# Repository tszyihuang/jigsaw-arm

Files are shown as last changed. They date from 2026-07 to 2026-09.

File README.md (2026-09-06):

# JigsawArm — 四轴机械臂视觉拼装系统

基于 **Jetson + YOLOv8 实例分割** 的四轴机械臂视觉拼装系统:摄像头实时识别散落的碎片 → 算法自动拼接并生成爆炸图 → 机械臂按坐标抓取、搬运、旋转放置,完成装配。全程无需人工干预坐标,`read` 一条命令跑完整流程。

<div align="center">

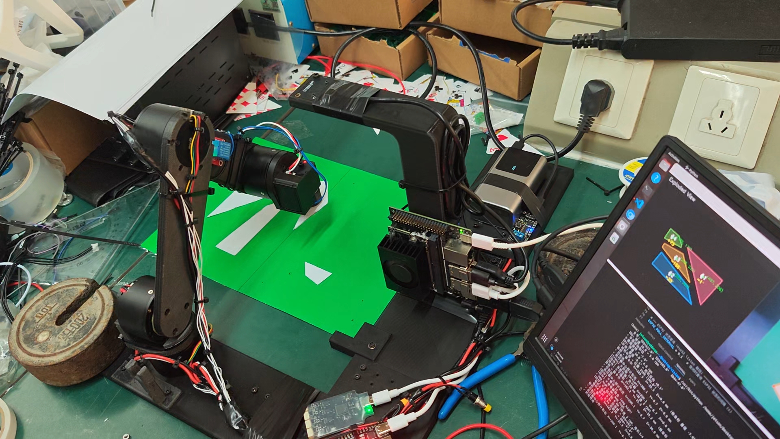
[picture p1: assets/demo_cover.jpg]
点击观看完赛演示视频(Bilibili:《26电赛E题机械臂完赛视频》) (https://www.bilibili.com/video/BV1Ag3Q6mEnW)


**▶ 完赛演示**:点击封面播放《26电赛E题机械臂完赛视频》,96 秒实拍展示机械臂自动拼装的完整流程。

</div>

## 项目简介

本项目是 **2026 年全国大学生电子设计竞赛(26 电赛)E 题** 作品代码库,基于 Jetson 平台实现图像识别、碎片拼接与机械臂自动装配等核心算法:

- **图像识别**:基于 YOLOv8 实例分割,实时识别散落碎片的轮廓与顶点
- **拼接算法**:DFS 回溯匹配边长度、面积比值与四边形角度,自动还原完整拼图并生成爆炸图
- **机械臂装配**:按拼接结果规划抓取、搬运、旋转与放置,自动完成装配

```
摄像头实时 YOLO 分割识别碎片
        │
        ▼
拼接 (DFS 回溯匹配边/面积/角度) + 爆炸图布局
        │
        ▼
输出每个碎片:原始坐标 → (爆炸图坐标, 旋转角)
        │
        ▼
机械臂 抓取 → 搬运 → 舵机旋转 → 放置, 完成装配
```

## 功能特性

- **GPU 实时分割**:YOLOv8 实例分割,GStreamer 硬件加速采集(640×480 @ 60fps),PyTorch CUDA 推理
- **跨帧时域平滑**:碎片顶点按轨迹做 EMA 平滑,抗单帧抖动
- **自动拼接算法**:DFS 回溯 — 边长度匹配 + 面积比值 + 四边形角度三重校验,输出对齐后的完整拼图
- **爆炸图布局**:碎片沿"整体中心→碎片中心"方向推出至外扩包围盒,直观展示每块的放置位置
- **一键装配**:`read` 流程连续采集 10 帧 → 平滑 → 拼接 → 爆炸图 → 独立进程弹窗三合一图,并输出每个碎片的抓取坐标、放置坐标与旋转角
- **绝对坐标控制**:控制台支持毫米级绝对笛卡尔坐标与相机像素坐标(仿射标定,残差 ~0.2mm)双模式
- **基座旋转 → 舵机反向补偿**:基座转动时工具自动反向补偿,保持被抓物体绝对姿态、防止线材缠绕
- **在线调参**:`pid_tune.py` 支持 GIM4310 位置/速度环 PID 在线读取、调整与掉电保存

## 系统架构

```
main_logic.py (业务/控制台) → arm_driver.CartesianArm (笛卡尔级)
    → arm_driver.Arm (电机级) → GIM4310_driver.MotorBus (RS485 总线)
```

- **笛卡尔级** (`CartesianArm`):`move_tool_to` / `move_camera_to`(像素→坐标)/ `go_standby` / `go_home`,分段移动与分关节延时,基座旋转→舵机补偿回调
- **电机级** (`Arm`):关节限位、上电编码器偏置检测、手腕水平参考(ID4 自动维持水平)
- **视觉** (`infer.py` + `reassemble.py`):YOLOv8 分割、顶点平滑、拼接、爆炸图

## 硬件与通信(三路串口 + 摄像头)

| 设备 | 协议/端口 | 说明 |
|---|---|---|
| 4× GIM4310 关节电机 | RS485, 115200, 8N1 | ID1 基座 / ID2 肩 / ID3 肘 / ID4 腕,协议见 `自定义RS485通信协议.md` |
| Feetech STS 工具旋转舵机 | 半双工 TTL, 1Mbps, ID=1 | 正 = 逆时针 |
| ESP32 | 115200, 自动检测端口 | 继电器(电磁铁抓取) + 红绿状态灯 |
| USB 摄像头 | /dev/video0, GStreamer | MJPG 硬件加速, 60fps |

> ⚠ 摄像头**不要两个进程同时打开**(实时窗口与 `read` 流程会互相抢占)。

## 环境依赖

- NVIDIA Jetson(带 CUDA 的 PyTorch)
- Python 3 + PyTorch (GPU) + ultralytics + OpenCV + pyserial + numpy

⚠ 必须使用带 GPU torch 的解释器(如 `/usr/bin/python3`),CPU 版 torch 无法实时推理。

## 快速开始

```bash
# 1. 单图拼接 + 爆炸图测试(无需硬件, 最快的验证方式)
/usr/bin/python3 reassemble.py <image_path>      # 输出 reassembled.jpg / exploded.jpg

# 2. 实时分割窗口
/usr/bin/python3 infer.py                        # q 退出 / s 截图 / r 跑 read 流程 / t 平滑开关

# 3. 主程序(启动流程 + 控制台控制, 需硬件)
/usr/bin/python3 main_logic.py                   # 自动检测 ESP32 串口
/usr/bin/python3 main_logic.py --esp-port /dev/ttyUSB0
/usr/bin/python3 main_logic.py --no              # 调试模式: 跳过视觉
```

### 控制台指令(main_logic.py)

| 指令 | 说明 |
|---|---|
| `<X> <Y> [Z]` | 绝对笛卡尔坐标(mm),Z 缺省保持当前 |
| `n <u> <v> [Z]` | 相机像素坐标 → 执行器坐标后移动 |
| `action` / `put` | 下降到抓取高度 → 继电器吸合/释放 → 回升 |
| `trans <u> <v> [角度]` | 搬运: 抓取点 → 放置点 → [舵机旋转角度] → 放下 |
| `transport <u1> <v1> <u2> <v2> [角度]` | 同 trans,放置点显式指定 |
| `r <角度>` | 舵机相对转动(正 = 逆时针) |
| `read` | 跑完整装配流程(等价于 infer.py 按 R) |
| `t1 ~ t4` | 把 read 输出的第 N 个碎片数据直接传入 transport 执行 |
| `home` / `standby` | 回到待机位置 |
| `ready` | 移动到准备位置 |
| `status` | 显示当前位置 |

`read` 输出格式:`#N(原始坐标)-(爆炸图坐标, 旋转角)`,旋转角约定**顺时针为正**,可直接作为 `trans` 角度使用。

## 项目结构

| 文件 | 作用 |
|---|---|
| `main_logic.py` | 主程序:启动流程 + 控制台指令解析 + 所有动作序列常量 |
| `arm_driver.py` | 机械臂驱动:FK/IK、极坐标换算、工具偏移、相机标定仿射 `CAMERA_A`、`Arm`(电机级)/`CartesianArm`(笛卡尔级) |
| `GIM4310_driver.py` | GIM4310 电机 RS485 驱动(`MotorBus`,地址 1-4) |
| `servo_driver.py` | Feetech STS 串口舵机驱动 |
| `infer.py` | YOLOv8 GPU 实时推理、顶点跨帧 EMA 平滑、`run_read_pipeline`(read 全流程) |
| `reassemble.py` | 碎片拼接(DFS 回溯)、爆炸图、三合一图 |
| `camera_driver.py` | 相机查看工具 |
| `host_test.py` | ESP32 串口通信测试 |
| `pid_tune.py` | GIM4310 PID 在线调参工具 |
| `view_image.py` | 独立进程图片查看器(infer 弹窗调用) |
| `自定义RS485通信协议.md` | GIM4310 RS485 自定义协议文档 |

## 关键约定

- **坐标系**:FK 镜像约定 `x = -r·cos(θ1), y = r·sin(θ1)`;基座角**增大 = 从摄像头视角看顺时针**
- **方向**:舵机**正 = 逆时针**;`read` 输出的旋转角**顺时针为正**(已在 `reassemble.py` 计算源头取反)
- **上电零点**:每次上电以电机当前位置为零点,须保证每次上电姿态一致(失能自由下垂),否则逻辑零点漂移
- **摄像头标定** `CAMERA_A` 为仿射最小二乘拟合(4 组标定点,残差 ~0.6px ≈ 0.2mm),**换机/换相机需重新标定**
- **移动分段**:去程先臂平面后基座,回程先基座后平面,避免工具偏移
- 所有动作参数(待机 Z、下降高度、转速、延时)集中在各文件顶部常量区,直接改常量即可

## 辅助工具

```bash
/usr/bin/python3 camera_driver.py   # 相机画面查看 (GStreamer MJPG 60fps)
/usr/bin/python3 host_test.py       # ESP32 串口测试 (--auto 自动检测)
/usr/bin/python3 pid_tune.py        # 电机 PID 调参
/usr/bin/python3 pid_tune.py --id 2 --pos-kp 60 --pos-ki 1 --save   # 调整 ID2 并保存
```

## 注意事项

- 必须使用带 GPU torch 的解释器,否则推理无法实时
- 摄像头同一时间只允许一个进程打开
- 上电前确保机械臂处于失能自由下垂姿态(零点以此为准)
- 串口路径、模型路径(`infer.py` 的 `MODEL_PATH`)为本地环境配置,换机部署时按需修改

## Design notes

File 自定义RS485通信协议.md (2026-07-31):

# 自定义RS485通信协议_V3.03b3

## 协议版本

*   **Rev.3.01b0 – 2024.01.06**：初始版本；
*   **Rev.3.01b1 – 2024.06.25**：添加更多通信数据帧例子；
*   **Rev.3.02b0 – 2024.11.21**：添加多摩川RS485协议编码器支持；添加抱闸输出控制命令；故障码添加编码器故障；
*   **Rev.3.02b1 – 2025.02.20**：更正文档中0x10命令码表格中命令码字段填写错误；
*   **Rev.3.02b2 – 2025.02.21**：更正0x10、0x11命令关于使能第二编码器的描述；
*   **Rev.3.02b3 – 2025.03.28**：完善通信示例；
*   **Rev.3.02b4 – 2025.04.24**：优化文档内容描述；
*   **Rev.3.03b0 – 2026.03.31**：增加MIT协议内容命令码0x30，0x31，0x32；增加位置速度控制命令码0x25、梯形曲线控制命令码0x26、位置滤波控制模式命令码0x27、位置滤波控制参数设置0x17；增加RS485通信超时配置0x2D；用户参数（命令码0x10、0x11）和电机硬件（命令0x12、0x13）参数的写入和读取内容做了变更；
*   **Rev.3.03b1 – 2026.05.22**：MIT协议内容命令码0x30增加对位置KP，速度KD最大值的设置；
*   **Rev.3.03b2 – 2026.05.27**：更正文档中MIT协议内容的错误描述；
*   **Rev.3.03b3 – 2026.06.09**：更正文档中的数据长度、CRC校验的错误描述；

---

## 协议简介

1.  **波特率与格式**：RS485接口默认通信波特率为**115200**（数据位：8，校验位：0，停止位：1）。可通过上位机的用户参数配置界面配置通信波特率为：921600，460800，115200，57600，38400，19200，9600。所有字节均采用**小端字节顺序**。
2.  **设备地址**：产品出货默认的设备地址为**0x01**。设备地址可通过上位机配置为 1-254；其中，设备地址 0 为广播地址，从机执行命令但不应答主机；设备地址 255 (0xFF) 为公共地址（所有从机均应答该地址命令），主机可单独使用该地址与从机通信获取配置参数。产品当前设备地址可以根据驱动板上绿色LED的闪烁状态获得：
    *   设备地址1：`[ __ -__-__ ]`
    *   设备地址2：`[ __-_-__-_-__ ]`
    *   设备地址3：`[ __-_-_-__-_-_-__ ]` 等。
3.  **总线特性说明**：RS485总线特性决定，总线上只能有一个主机，且从机设备地址不能相同。如果总线有多个设备地址一样的从机，主机通过该地址与从机通信，设备地址相同从机会同时应答主机，从而导致总线短路损坏控制板。因此，**当多个从机挂载在同一总线上时，需提前通过上位机或通信协议配置好从机的设备地址**。

### RS485_V3.x 版本协议通信数据包的命令格式如下：

| 字段名 | 字节数 | 说明 |
| :--- | :--- | :--- |
| **协议头** | 1Byte | 主机发送的协议头为 **0xAE**，从机应答的协议头为 **0xAC**； |
| **包序号** | 1Byte | 从机应答主机的包序号与主机发送给从机的包序号一致； |
| **设备地址** | 1Byte | 地址范围为 0-0xFF；0x00 为广播地址；0xFF 为公共地址；<br>**广播地址**：从机均能收到指令并执行指令，但不应答主机；<br>**公共地址**：从机均能收到指令并执行指令，但应答主机；RS485总线特性决定，当总线连接多个电机时，不能使用公共地址； |
| **命令码** | 1Byte | 不同的命令有不同的命令码； |
| **数据包长度** | 1Byte | 【数据字段】字节数量（可以为0）； |
| **数据字段** | 0-248 (Byte) | 命令码附带的数据； |
| **CRC16校验** | 2Byte | 【协议头】至【数据字段】**CRC16_MODBUS**校验值；校验计算可参考资料包《CRC16_MODBUS校验C语言源码》 |

### 数据类型说明：
*   **1u** – 1个无符号字节
*   **1s** – 1个有符号字节
*   **2u** – 2个无符号字节（小端字节顺序）
*   **2s** – 2个有符号字节（小端字节顺序）
*   **4u** – 4个无符号字节（小端字节顺序）
*   **4s** – 4个有符号字节（小端字节顺序）
*   **4f** – 单精度浮点数（小端字节顺序）
*   **Nb** – 大小为 N 的字节数组

---

## RS485_3.x 版本协议控制命令如下：

| 类别 | 命令码 | 命令功能描述 |
| :---: | :---: | :--- |
| **系统** | **0x00** | 重启从机，主控制器发送该命令包后，从机立即重启不应答主控制器 |
| | **0x0A** | 读取Boot、软件、硬件、RS485协议和CAN协议版本及UID； |
| | **0x0B** | 读单圈绝对值角度、多圈绝对值角度、速度、Q轴电流等实时信息； |
| | **0x0F** | 清除故障； |
| **参数** | **0x10** | 读取用户参数； |
| | **0x11** | 写入并保存用户参数； |
| | **0x12** | 读取电机硬件参数； |
| | **0x13** | 写入并保存电机硬件参数； |
| | **0x14** | 读取运动控制参数； |
| | **0x15** | 写入运动控制参数但不保存； |
| | **0x16** | 写入并保存运动控制参数； |
| | **0x17** | 位置滤波控制参数的读取和配置，断电不保存； |
| | **0x1D** | 设置当前位置为原点； |
| | **0x1E** | 编码器校准；校准过程中电机需空载，且不能干扰电机转动； |
| | **0x1F** | 参数恢复默认值； |
| **控制** | **0x20** | Q轴电流控制；（力矩 = 力矩常数 * Q轴电流） |
| | **0x21** | 速度控制； |
| | **0x22** | 绝对值位置控制； |
| | **0x23** | 相对位置控制； |
| | **0x24** | 电机按照最短的距离回到设定的原点，旋转的角度不大于180度； |
| | **0x25** | 位置速度控制； |
| | **0x26** | 梯形曲线位置控制； |
| | **0x27** | 位置滤波控制； |
| | **0x2D** | RS485通信超时使能、时长、动作类型的读取和配置，断电不保存 |
| | **0x2E** | 抱闸控制开关输出控制； |
| | **0x2F** | 关闭电机输出，电机进入自由态不受控制（电机上电后为该状态）； |
| **运控MIT协议** | **0x30** | 运控模式控制指令中的Pos_Max、Vel_Max、T_Max、Pos_KP_Max、Vel_KD_Max的读取和配置，断电保存； |
| | **0x31** | 读取运控模式下的实时位置、速度、力矩和状态信息； |
| | **0x32** | 运控模式协议控制； |

---

## 协议命令详细说明

### 重启从机；【命令码:0x00】
主控制器发送该命令包后，从机立即重启不应答主控制器。

#### 1. 主控制器(上位机)发送给从机(下位机)
| 序号 | 字段名称 | 类型 | 内容说明(数据) |
| :---: | :--- | :---: | :--- |
| [0] | 协议头 | 1u | 0xAE |
| [1] | 包序号 | 1u | 0x00~0xFF |
| [2] | 设备地址 | 1u | 0x01~0xFE |
| [3] | 命令码 | 1u | **0x00** |
| [4] | 数据包长度 | 1u | 0x00 |
| [5]-[6] | CRC16校验 | 2u | DATA[0]~DATA[4]字节CRC16校验 |

---

### 读取Boot、软件、硬件、RS485协议和CAN协议版本以及唯一序列号；【命令码:0x0A】

#### 1. 主控制器(上位机)发送给从机(下位机)
| 序号 | 字段名称 | 类型 | 内容说明(数据) |
| :---: | :--- | :---: | :--- |
| [0] | 协议头 | 1u | 0xAE |
| [1] | 包序号 | 1u | 0x00~0xFF |
| [2] | 设备地址 | 1u | 0x01~0xFE |
| [3] | 命令码 | 1u | **0x0A** |
| [4] | 数据包长度 | 1u | 0x00 |
| [5]-[6] | CRC16校验 | 2u | DATA[0]~DATA[4]字节CRC16校验 |

#### 2. 从机(下位机)应答主控制器(上位机)
| 序号 | 字段名称 | 类型 | 内容说明(数据) |
| :---: | :--- | :---: | :--- |
| [0] | 协议头 | 1u | 0xAC |
| [1] | 包序号 | 1u | 0x00~0xFF |
| [2] | 设备地址 | 1u | 0x01~0xFE |
| [3] | 命令码 | 1u | **0x0A** |
| [4] | 数据包长度 | 1u | 0x16 |
| [5]-[6] | Boot软件版本 | 2u | |
| [7]-[8] | 应用软件版本 | 2u | |
| [9]-[10] | 硬件型号 | 2u | 驱动板硬件代号； |
| [11] | RS485-自定义 | 1u | RS485-自定义协议版本； |
| [12] | RS485-Modbus | 1u | RS485-Modbus协议版本；（0表示不支持） |
| [13] | CAN-自定义 | 1u | CAN-自定义协议版本； |
| [14] | CAN-CanOpen | 1u | CanOpen协议版本；（0表示不支持） |
| [15]-[26]| UID唯一序列号| 12b | 唯一设备序列号 |
| [27]-[28]| CRC16校验 | 2u | DATA[0]~DATA[26]字节CRC16校验 |

---

### 读取实时数据；单圈分辨率为14位；【命令码:0x0B】
（单圈绝对值角度、多圈绝对值角度、速度、Q轴电流、母线电压、母线电流、工作温度、运行状态、电机状态、故障码）

#### 1. 主控制器(上位机)发送给从机(下位机)
| 序号 | 字段名称 | 类型 | 内容说明(数据) |
| :---: | :--- | :---: | :--- |
| [0] | 协议头 | 1u | 0xAE |
| [1] | 包序号 | 1u | 0x00~0xFF |
| [2] | 设备地址 | 1u | 0x01~0xFE |
| [3] | 命令码 | 1u | **0x0B** |
| [4] | 数据包长度 | 1u | 0x00 |
| [5]-[6] | CRC16校验 | 2u | DATA[0]~DATA[4]字节CRC16校验 |

#### 2. 从机(下位机)应答主控制器(上位机)
| 序号 | 字段名称 | 类型 | 内容说明(数据) |
| :---: | :--- | :---: | :--- |
| [0] | 协议头 | 1u | 0xAC |
| [1] | 包序号 | 1u | 0x00~0xFF |
| [2] | 设备地址 | 1u | 0x01~0xFE |
| [3] | 命令码 | 1u | **0x0B** |
| [4] | 数据包长度 | 1u | 0x16 |
| [5]-[6] | 单圈绝对值角度| 2u | Angle° = value * (360/16384)； |
| [7]-[10]| 多圈绝对值角度| 4s | Total Angle° = value * (360/16384)； |
| [11]-[14]| 机械速度 | 4s | 单位 0.01rpm； |
| [15]-[18]| Q轴电流 | 4s | 单位 0.001A；（力矩 = Q轴电流 * 力矩常数） |
| [19]-[20]| 母线电压 | 2u | 单位 0.01V； |
| [21]-[22]| 母线电流 | 2u | 单位 0.01A；编码器校准过程中该值无效； |
| [23] | 工作温度 | 1u | 单位 ℃； |
| [24] | 运行状态 | 1u | 0:关闭状态 1:电压控制 2:Q轴电流控制 3:速度控制 4:位置控制 |
| [25] | 电机状态 | 1u | 0:失能 其他:使能 |
| [26] | 故障码 | 1u | [Bit0]: 电压故障 [Bit1]: 电流故障 [Bit2]: 温度故障 [Bit3]: 编码器故障 [Bit6]: 硬件故障 [Bit7]: 软件故障 （Bitn表示字节的第n位；Bit0表示第0位） |
| [27]-[28]| CRC16校验 | 2u | DATA[0]~DATA[26]字节CRC16校验 |

---

### 清除故障；【命令码:0x0F】

#### 1. 主控制器(上位机)发送给从机(下位机)
| 序号 | 字段名称 | 类型 | 内容说明(数据) |
| :---: | :--- | :---: | :--- |
| [0] | 协议头 | 1u | 0xAE |
| [1] | 包序号 | 1u | 0x00~0xFF |
| [2] | 设备地址 | 1u | 0x01~0xFE |
| [3] | 命令码 | 1u | **0x0F** |
| [4] | 数据包长度 | 1u | 0x00 |
| [5]-[6] | CRC16校验 | 2u | DATA[0]~DATA[4]字节CRC16校验 |

#### 2. 从机(下位机)应答主控制器(上位机)
| 序号 | 字段名称 | 类型 | 内容说明(数据) |
| :---: | :--- | :---: | :--- |
| [0] | 协议头 | 1u | 0xAC |
| [1] | 包序号 | 1u | 0x00~0xFF |
| [2] | 设备地址 | 1u | 0x01~0xFE |
| [3] | 命令码 | 1u | **0x0F** |
| [4] | 数据包长度 | 1u | 0x01 |
| [5] | 当前故障 | 1u | 位定义同0x0B中的故障码。0x00表示清除成功。 |
| [6]-[7] | CRC16校验 | 2u | DATA[0]~DATA[5]字节CRC16校验 |

---

### 读取用户参数；【命令码:0x10】

#### 1. 主控制器(上位机)发送给从机(下位机)
| 序号 | 字段名称 | 类型 | 内容说明(数据) |
| :---: | :--- | :---: | :--- |
| [0] | 协议头 | 1u | 0xAE |
| [1] | 包序号 | 1u | 0x00~0xFF |
| [2] | 设备地址 | 1u | 0x01~0xFE |
| [3] | 命令码 | 1u | **0x10** |
| [4] | 数据包长度 | 1u | 0x02 |
| [5] | 协议版本 | 1u | V1:0x01；V2:0x02；V3:0x03；不同版本包含内容不同，高版本包含低版本所有内容。 |
| [6] | 保留 | 1u | |
| [7]-[8] | CRC16校验 | 2u | DATA[0]~DATA[6]字节CRC16校验 |

#### 2. 从机(下位机)应答主控制器(上位机)
| 版本区分 | 序号 | 字段名称 | 类型 | 内容说明(数据) |
| :---: | :---: | :--- | :---: | :--- |
| | [0] | 协议头 | 1u | 0xAC |
| | [1] | 包序号 | 1u | 0x00~0xFF |
| | [2] | 设备地址 | 1u | 0x01~0xFE |
| | [3] | 命令码 | 1u | **0x10** |
| | [4] | 数据包长度 | 1u | 0x1C (V1/V2); 0x1E (V3) |
| **V1/V2** | [5]-[6] | 电角度偏移 | 2u | 编码器校准得到的角度偏移； |
| | [7]-[8] | 机械角度偏移| 2u | 零点设置得到的角度偏移； |
| | [9]-[10]| U相电流偏移 | 2u | U相电流校准得到的偏移； |
| | [11]-[12]| V相电流偏移 | 2u | V相电流校准得到的偏移； |
| | [13]-[14]| W相电流偏移 | 2u | W相电流校准得到的偏移； |
| | [15] | 编码器型号 | 1u | 0: AS504x_SPI; 1: Ma7xx_SPI; 2: MT6835_SPI; 3: TLx5012_SSI; 4: AS504x_PWM; 5: Tamagawa |
| | [16] | 改变编码器方向| 1u | 0:不改变方向； 其它:改变方向； |
| | [17] | 使能第二编码器| 1u | 0:不使能； 其它:使能； |
| | [18] | 速度滤波系数 | 1u | 数值1~100表示系数0.01~1； |
| | [19] | 设备地址 | 1u | 地址范围为0x01~0xFE (1~254)； |
| | [20] | RS485波特率 | 1u | 0: 921600; 1: 460800; 2: 115200; 3: 57600; 4: 38400; 5: 19200; 6: 9600 (默认115200) |
| | [21] | CAN波特率 | 1u | 0: 1M; 1: 500K; 2: 250K; 3: 125K; 4: 100K (默认1M) |
| | [22] | 功能拓展 | 1u | [bit0]: CANopen功能； 其它:预留； 置高为开启 |
| | [23]-[24]| 最大母线电压 | 2u | 单位为0.01V |
| | [25] | 报电压故障时长| 1u | 持续过压时长大于该时长，报故障；单位秒； |
| | [26]-[27]| 最大母线电流 | 2u | 单位为0.01A |
| | [28] | 报电流故障时长| 1u | 持续过流时长大于该时长，报故障；单位秒； |
| | [29] | 最大温度 | 1u | 最大温度，单位℃； |
| | [30] | 报温度故障时长| 1u | 持续过温时长大于该时长，报故障；单位秒； |
| **V3** | [31]-[32]| 电流环增益 | 2u | 单位rad/s，为0表示使用电压环 |
| | [33]-[34]| CRC16校验 | 2u | DATA[0]~DATA[32]字节CRC16校验 |

---

### 写入并保存用户参数；【命令码:0x11】

#### 1. 主控制器(上位机)发送给从机(下位机)
主机发送的数据包格式、字段偏移和类型与 **0x10命令的应答格式完全一致**，除了命令码为 **0x11**，数据包长度在V1/V2版本下为0x1A，在V3版本下为0x1C（即不包含前4个协议字段，从第[5]个字节即参数内容开始传输）。

*   **数据包长度 [4]**: V1/V2为 `0x12`，V3为 `0x14`。
*   **具体结构**：同 0x10 从机应答的数据字段 [5] ~ [30](V1/V2) 或 [32](V3)。

#### 2. 从机(下位机)应答主控制器(上位机)
除了应答的命令码不同外，从机应答主机的内容与0x10命令的内容一致。

---

### 读取电机硬件参数；【命令码:0x12】

#### 1. 主控制器(上位机)发送给从机(下位机)
| 序号 | 字段名称 | 类型 | 内容说明(数据) |
| :---: | :--- | :---: | :--- |
| [0] | 协议头 | 1u | 0xAE |
| [1] | 包序号 | 1u | 0x00~0xFF |
| [2] | 设备地址 | 1u | 0x01~0xFE |
| [3] | 命令码 | 1u | **0x12** |
| [4] | 数据包长度 | 1u | 0x00 |
| [5]-[6] | CRC16校验 | 2u | DATA[0]~DATA[4]字节CRC16校验 |

#### 2. 从机(下位机)应答主控制器(上位机)
| 版本区分 | 序号 | 字段名称 | 类型 | 内容说明(数据) |
| :---: | :---: | :--- | :---: | :--- |
| | [0] | 协议头 | 1u | 0xAC |
| | [1] | 包序号 | 1u | 0x00~0xFF |
| | [2] | 设备地址 | 1u | 0x01~0xFE |
| | [3] | 命令码 | 1u | **0x12** |
| | [4] | 数据包长度 | 1u | 0x21 (V3) / 0x1E (V1/V2) |
| **V1/V2** | [5]-[20] | 电机名称 | Nb | 电机名称的ASCII字符 |
| | [21] | 电机极对数 | 1u | |
| | [22]-[25]| 相电阻 | 4f | 两相之间的电阻/2；单位为Ω； |
| | [26]-[29]| 相电感 | 4f | 两相之间的电感/2；单位为mH； |
| | [30]-[33]| 力矩常数 | 4f | 单位为 N·m/A； |
| **V3** | [34] | 减速比 | 1u | 减速比分子低8位 |
| | [35] | 减速比 | 1u | 减速比分子高8位 |
| | [36]-[37]| 减速比 | 2u | 减速比分母 |
| | [38]-[39]| CRC16校验 | 2u | DATA[0]~DATA[37]字节CRC16校验 |

---

### 写入并保存电机硬件参数；【命令码:0x13】

#### 1. 主控制器(上位机)发送给从机(下位机)
*   **命令码 [3]**: **0x13**
*   **数据包长度 [4]**: V1/V2为 `0x1E`，V3为 `0x21`。
*   **字段内容**: 与0x12应答格式相同（去除通信包头）。

#### 2. 从机(下位机)应答主控制器(上位机)
除了应答的命令码不同外，从机应答主机的内容与0x12命令的内容一致。

---

### 读取运动控制参数；【命令码:0x14】

#### 1. 主控制器(上位机)发送给从机(下位机)
| 序号 | 字段名称 | 类型 | 内容说明(数据) |
| :---: | :--- | :---: | :--- |
| [0] | 协议头 | 1u | 0xAE |
| [1] | 包序号 | 1u | 0x00~0xFF |
| [2] | 设备地址 | 1u | 0x01~0xFE |
| [3] | 命令码 | 1u | **0x14** |
| [4] | 数据包长度 | 1u | 0x00 |
| [5]-[6] | CRC16校验 | 2u | DATA[0]~DATA[4]字节CRC16校验 |

#### 2. 从机(下位机)应答主控制器(上位机)
| 序号 | 字段名称 | 类型 | 内容说明(数据) |
| :---: | :--- | :---: | :--- |
| [0] | 协议头 | 1u | 0xAC |
| [1] | 包序号 | 1u | 0x00~0xFF |
| [2] | 设备地址 | 1u | 0x01~0xFE |
| [3] | 命令码 | 1u | **0x14** |
| [4] | 数据包长度 | 1u | 0x18 |
| [5]-[8] | 位置环Kp | 4f | |
| [9]-[12] | 位置环Ki | 4f | |
| [13]-[16]| 位置环输出限制| 4u | 位置模式最大速度，单位为 0.01rpm； |
| [17]-[20]| 速度环Kp | 4f | |
| [21]-[24]| 速度环Ki | 4f | |
| [25]-[28]| 速度环输出限制| 4u | 速度/位置模式最大Q轴电流，单位 0.001A； |
| [29]-[30]| CRC16校验 | 2u | DATA[0]~DATA[28]字节CRC16校验 |

---

### 写入运动控制参数但不保存；【命令码:0x15】

#### 1. 主控制器(上位机)发送给从机(下位机)
| 序号 | 字段名称 | 类型 | 内容说明(数据) |
| :---: | :--- | :---: | :--- |
| [0] | 协议头 | 1u | 0xAE |
| [1] | 包序号 | 1u | 0x00~0xFF |
| [2] | 设备地址 | 1u | 0x01~0xFE |
| [3] | 命令码 | 1u | **0x15** |
| [4] | 数据包长度 | 1u | 0x18 |
| [5]-[8] | 位置环Kp | 4f | |
| [9]-[12] | 位置环Ki | 4f | |
| [13]-[16]| 位置环输出限制| 4u | 位置模式最大速度，单位为 0.01rpm； |
| [17]-[20]| 速度环Kp | 4f | |
| [21]-[24]| 速度环Ki | 4f | |
| [25]-[28]| 速度环输出限制| 4u | 速度/位置模式最大Q轴电流，单位 0.001A； |
| [29]-[30]| CRC16校验 | 2u | DATA[0]~DATA[28]字节CRC16校验 |

#### 2. 从机(下位机)应答主控制器(上位机)
除了应答的命令码不同外，从机应答主机的内容与0x14命令的内容一致。

---

### 写入并保存运动控制参数；【命令码:0x16】

#### 1. 主控制器(上位机)发送给从机(下位机)
除了发送的命令码（**0x16**）不同外，主机发送给从机的内容与0x15命令的内容一致；

#### 2. 从机(下位机)应答主控制器(上位机)
除了应答的命令码不同外，从机应答主机的内容与0x14命令的内容一致；

---

### 位置滤波控制参数的读取和配置，断电不保存；【命令码:0x17】

#### 1. 主控制器(上位机)发送给从机(下位机)
| 序号 | 字段名称 | 类型 | 内容说明(数据) |
| :---: | :--- | :---: | :--- |
| [0] | 协议头 | 1u | 0xAE |
| [1] | 包序号 | 1u | 0x00~0xFF |
| [2] | 设备地址 | 1u | 0x01~0xFE |
| [3] | 命令码 | 1u | **0x17** |
| [4] | 数据包长度 | 1u | **[0x00，读取参数]**、**[0x0A，配置参数]** |
| [5]-[6] | 位置滤波带宽 | 2u | 位置滤波带宽，单位为Hz；默认50Hz； |
| [7]-[10]| 位置滤波转动惯量| 4f | 转动惯量，单位为 N·m/(turn/s²)，0表示禁用电流前馈；默认0.001N·m/(turn/s²)； |
| [11]-[14]| 位置滤波控制电流前馈限制 | 4u | 位置滤波模式最大前馈电流，单位0.001A；默认1A； |
| [15]-[16]| CRC16校验 | 2u | DATA[0]~DATA[14]字节CRC16校验 |

#### 2. 从机(下位机)应答主控制器(上位机)
| 序号 | 字段名称 | 类型 | 内容说明(数据) |
| :---: | :--- | :---: | :--- |
| [0] | 协议头 | 1u | 0xAC |
| [1] | 包序号 | 1u | 0x00~0xFF |
| [2] | 设备地址 | 1u | 0x01~0xFE |
| [3] | 命令码 | 1u | **0x17** |
| [4] | 数据包长度 | 1u | 0x0A |
| [5]-[6] | 位置滤波带宽 | 2u | 位置滤波带宽，单位为Hz |
| [7]-[10]| 位置滤波转动惯量| 4f | 转动惯量，单位为 N·m/(turn/s²)，0表示禁用电流前馈 |
| [11]-[14]| 位置滤波控制电流前馈限制 | 4u | 位置滤波模式最大前馈电流，单位0.001A； |
| [15]-[16]| CRC16校验 | 2u | DATA[0]~DATA[14]字节CRC16校验 |

---

### 设置当前位置为原点；【命令码:0x1D】

#### 1. 主控制器(上位机)发送给从机(下位机)
| 序号 | 字段名称 | 类型 | 内容说明(数据) |
| :---: | :--- | :---: | :--- |
| [0] | 协议头 | 1u | 0xAE |
| [1] | 包序号 | 1u | 0x00~0xFF |
| [2] | 设备地址 | 1u | 0x01~0xFE |
| [3] | 命令码 | 1u | **0x1D** |
| [4] | 数据包长度 | 1u | 0x00 |
| [5]-[6] | CRC16校验 | 2u | DATA[0]~DATA[4]字节CRC16校验 |

#### 2. 从机(下位机)应答主控制器(上位机)
| 序号 | 字段名称 | 类型 | 内容说明(数据) |
| :---: | :--- | :---: | :--- |
| [0] | 协议头 | 1u | 0xAC |
| [1] | 包序号 | 1u | 0x00~0xFF |
| [2] | 设备地址 | 1u | 0x01~0xFE |
| [3] | 命令码 | 1u | **0x1D** |
| [4] | 数据包长度 | 1u | 0x02 |
| [5]-[6] | 机械角度偏移 | 2u | 设定原点后当前电机的电偏移量/偏移角 |
| [7]-[8] | CRC16校验 | 2u | DATA[0]~DATA[6]字节CRC16校验 |

---

### 编码器校准；【命令码:0x1E】
考虑到校准结果的准确性，编码器校准过程中电机需空载，且不能干扰电机转动；如需停止当前编码器校准，可发送0x2F命令停止操作。

#### 1. 主控制器(上位机)发送给从机(下位机)
| 序号 | 字段名称 | 类型 | 内容说明(数据) |
| :---: | :--- | :---: | :--- |
| [0] | 协议头 | 1u | 0xAE |
| [1] | 包序号 | 1u | 0x00~0xFF |
| [2] | 设备地址 | 1u | 0x01~0xFE |
| [3] | 命令码 | 1u | **0x1E** |
| [4] | 数据包长度 | 1u | 0x00 |
| [5]-[6] | CRC16校验 | 2u | DATA[0]~DATA[4]字节CRC16校验 |

#### 2. 从机(下位机)应答主控制器(上位机)
除了应答的命令码不同外，从机应答主机的内容与0x0B命令的内容一致；

---

### 参数恢复默认值；【命令码:0x1F】
（设备地址、编码器校准参数、电机硬件参数不变）

#### 1. 主控制器(上位机)发送给从机(下位机)
| 序号 | 字段名称 | 类型 | 内容说明(数据) |
| :---: | :--- | :---: | :--- |
| [0] | 协议头 | 1u | 0xAE |
| [1] | 包序号 | 1u | 0x00~0xFF |
| [2] | 设备地址 | 1u | 0x01~0xFE |
| [3] | 命令码 | 1u | **0x1F** |
| [4] | 数据包长度 | 1u | 0x00 |
| [5]-[6] | CRC16校验 | 2u | DATA[0]~DATA[4]字节CRC16校验 |

#### 2. 从机(下位机)应答主控制器(上位机)
| 序号 | 字段名称 | 类型 | 内容说明(数据) |
| :---: | :--- | :---: | :--- |
| [0] | 协议头 | 1u | 0xAC |
| [1] | 包序号 | 1u | 0x00~0xFF |
| [2] | 设备地址 | 1u | 0x01~0xFE |
| [3] | 命令码 | 1u | **0x1F** |
| [4] | 数据包长度 | 1u | 0x00 |
| [5]-[6] | CRC16校验 | 2u | DATA[0]~DATA[4]字节CRC16校验 |

---

### Q轴电流控制；【命令码:0x20】

#### 1. 主控制器(上位机)发送给从机(下位机)
| 序号 | 字段名称 | 类型 | 内容说明(数据) |
| :---: | :--- | :---: | :--- |
| [0] | 协议头 | 1u | 0xAE |
| [1] | 包序号 | 1u | 0x00~0xFF |
| [2] | 设备地址 | 1u | 0x01~0xFE |
| [3] | 命令码 | 1u | **0x20** |
| [4] | 数据包长度 | 1u | 0x08 |
| [5]-[8] | 目标Q轴电流 | 4s | 单位0.001A；力矩 = 目标电流 * 力矩常数； |
| [9]-[12] | Q轴电流斜率 | 4u | 单位0.001A/S；值为0时为最大斜率； |
| [13]-[14]| CRC16校验 | 2u | DATA[0]~DATA[12]字节CRC16校验 |

#### 2. 从机(下位机)应答主控制器(上位机)
除了应答的命令码不同外，从机应答主机的内容与0x0B命令的内容一致；

---

### 速度控制；【命令码:0x21】

#### 1. 主控制器(上位机)发送给从机(下位机)
| 序号 | 字段名称 | 类型 | 内容说明(数据) |
| :---: | :--- | :---: | :--- |
| [0] | 协议头 | 1u | 0xAE |
| [1] | 包序号 | 1u | 0x00~0xFF |
| [2] | 设备地址 | 1u | 0x01~0xFE |
| [3] | 命令码 | 1u | **0x21** |
| [4] | 数据包长度 | 1u | 0x08 |
| [5]-[8] | 目标速度 | 4s | 单位为0.01rpm； |
| [9]-[12] | 加速度 | 4u | 单位为0.01rpm/s；值为0为最大加速度； |
| [13]-[14]| CRC16校验 | 2u | DATA[0]~DATA[12]字节CRC16校验 |

#### 2. 从机(下位机)应答主控制器(上位机)
除了应答的命令码不同外，从机应答主机的内容与0x0B命令的内容一致；

---

### 绝对值位置控制；【命令码:0x22】

#### 1. 主控制器(上位机)发送给从机(下位机)
| 序号 | 字段名称 | 类型 | 内容说明(数据) |
| :---: | :--- | :---: | :--- |
| [0] | 协议头 | 1u | 0xAE |
| [1] | 包序号 | 1u | 0x00~0xFF |
| [2] | 设备地址 | 1u | 0x01~0xFE |
| [3] | 命令码 | 1u | **0x22** |
| [4] | 数据包长度 | 1u | 0x04 |
| [5]-[8] | 绝对值位置 | 4s | 单位为Count；旋转一圈为16384Count； |
| [9]-[10] | CRC16校验 | 2u | DATA[0]~DATA[8]字节CRC16校验 |

#### 2. 从机(下位机)应答主控制器(上位机)
除了应答的命令码不同外，从机应答主机的内容与0x0B命令的内容一致；

---

### 相对位置控制；【命令码:0x23】

#### 1. 主控制器(上位机)发送给从机(下位机)
| 序号 | 字段名称 | 类型 | 内容说明(数据) |
| :---: | :--- | :---: | :--- |
| [0] | 协议头 | 1u | 0xAE |
| [1] | 包序号 | 1u | 0x00~0xFF |
| [2] | 设备地址 | 1u | 0x01~0xFE |
| [3] | 命令码 | 1u | **0x23** |
| [4] | 数据包长度 | 1u | 0x04 |
| [5]-[8] | 相对位置 | 4s | 单位为Count；旋转一圈为16384Count； |
| [9]-[10] | CRC16校验 | 2u | DATA[0]~DATA[8]字节CRC16校验 |

#### 2. 从机(下位机)应答主控制器(上位机)
除了应答的命令码不同外，从机应答主机的内容与0x0B命令的内容一致；

---

### 最短距离回原点；【命令码:0x24】

#### 1. 主控制器(上位机)发送给从机(下位机)
| 序号 | 字段名称 | 类型 | 内容说明(数据) |
| :---: | :--- | :---: | :--- |
| [0] | 协议头 | 1u | 0xAE |
| [1] | 包序号 | 1u | 0x00~0xFF |
| [2] | 设备地址 | 1u | 0x01~0xFE |
| [3] | 命令码 | 1u | **0x24** |
| [4] | 数据包长度 | 1u | 0x00 |
| [5]-[6] | CRC16校验 | 2u | DATA[0]~DATA[4]字节CRC16校验 |

#### 2. 从机(下位机)应答主控制器(上位机)
除了应答的命令码不同外，从机应答主机的内容与0x0B命令的内容一致；

---

### 位置速度控制；【命令码:0x25】

#### 1. 主控制器(上位机)发送给从机(下位机)
| 序号 | 字段名称 | 类型 | 内容说明(数据) |
| :---: | :--- | :---: | :--- |
| [0] | 协议头 | 1u | 0xAE |
| [1] | 包序号 | 1u | 0x00~0xFF |
| [2] | 设备地址 | 1u | 0x01~0xFE |
| [3] | 命令码 | 1u | **0x25** |
| [4] | 数据包长度 | 1u | 0x09 |
| [5] | 位置类型 | 1u | [00 : 绝对值位置] [01 : 相对值位置] |
| [6]-[9] | 目标位置 | 4s | 单位为Count；旋转一圈为16384Count； |
| [10]-[13]| 目标速度 | 4u | 单位为0.01rpm |
| [14]-[15]| CRC16校验 | 2u | DATA[0]~DATA[13]字节CRC16校验 |

#### 2. 从机(下位机)应答主控制器(上位机)
除了应答的命令码不同外，从机应答主机的内容与0x0B命令的内容一致；

---

### 梯形曲线位置控制；【命令码:0x26】

#### 1. 主控制器(上位机)发送给从机(下位机)
| 序号 | 字段名称 | 类型 | 内容说明(数据) |
| :---: | :--- | :---: | :--- |
| [0] | 协议头 | 1u | 0xAE |
| [1] | 包序号 | 1u | 0x00~0xFF |
| [2] | 设备地址 | 1u | 0x01~0xFE |
| [3] | 命令码 | 1u | **0x26** |
| [4] | 数据包长度 | 1u | 0x11 |
| [5] | 位置类型 | 1u | [00 : 绝对值位置] [01 : 相对值位置] |
| [6]-[9] | 目标位置 | 4s | 单位为Count；旋转一圈为16384Count； |
| [10]-[13]| 最大速度 | 4u | 单位为0.01rpm |
| [14]-[17]| 最大加速度 | 4u | 单位为0.01rpm/s |
| [18]-[21]| 最大减速度 | 4u | 单位为0.01rpm/s |
| [22]-[23]| CRC16校验 | 2u | DATA[0]~DATA[21]字节CRC16校验 |

#### 2. 从机(下位机)应答主控制器(上位机)
除了应答的命令码不同外，从机应答主机的内容与0x0B命令的内容一致；

---

### 位置滤波控制；【命令码:0x27】

#### 1. 主控制器(上位机)发送给从机(下位机)
| 序号 | 字段名称 | 类型 | 内容说明(数据) |
| :---: | :--- | :---: | :--- |
| [0] | 协议头 | 1u | 0xAE |
| [1] | 包序号 | 1u | 0x00~0xFF |
| [2] | 设备地址 | 1u | 0x01~0xFE |
| [3] | 命令码 | 1u | **0x27** |
| [4] | 数据包长度 | 1u | 0x09 |
| [5] | 位置类型 | 1u | [00 : 绝对值位置] [01 : 相对值位置] |
| [6]-[9] | 目标位置 | 4s | 单位为Count；旋转一圈为16384Count； |
| [10]-[13]| 最大速度 | 4u | 单位为0.01rpm； |
| [14]-[15]| CRC16校验 | 2u | DATA[0]~DATA[13]字节CRC16校验 |

#### 2. 从机(下位机)应答主控制器(上位机)
除了应答的命令码不同外，从机应答主机的内容与0x0B命令的内容一致；

---

### RS485通信超时使能、时长、动作类型的读取和配置，断电不保存；【命令码:0x2D】

#### 1. 主控制器(上位机)发送给从机(下位机)
| 序号 | 字段名称 | 类型 | 内容说明(数据) |
| :---: | :--- | :---: | :--- |
| [0] | 协议头 | 1u | 0xAE |
| [1] | 包序号 | 1u | 0x00~0xFF |
| [2] | 设备地址 | 1u | 0x01~0xFE |
| [3] | 命令码 | 1u | **0x2D** |
| [4] | 数据包长度 | 1u | **[0x00, 读取参数]**、**[0x04, 配置参数]** |
| [5] | 通信超时使能 | 1u | 0x00: 失能 0x01: 使能；默认为失能 |
| [6]-[7] | 时长 | 2u | 单位ms；默认为5000ms |
| [8] | 动作类型 | 1u | 超时使能且时长大于设定值，报通信故障并失能电机；<br>可配置附加动作：<br>[Bit0]：通信故障码不允许软件清除；<br>[Bit1]：抱闸开关断开；<br>默认为0x00，没有任何额外动作； |
| [9]-[10] | CRC16校验 | 2u | DATA[0]~DATA[8]字节CRC16校验 |

#### 2. 从机(下位机)应答主控制器(上位机)
| 序号 | 字段名称 | 类型 | 内容说明(数据) |
| :---: | :--- | :---: | :--- |
| [0] | 协议头 | 1u | 0xAC |
| [1] | 包序号 | 1u | 0x00~0xFF |
| [2] | 设备地址 | 1u | 0x01~0xFE |
| [3] | 命令码 | 1u | **0x2D** |
| [4] | 数据包长度 | 1u | 0x04 |
| [5] | 通信超时使能 | 1u | 0x00: 失能 0x01: 使能 |
| [6]-[7] | 时长 | 2u | 单位ms； |
| [8] | 动作类型 | 1u | [Bit0]：通信故障码不允许软件清除； [Bit1]：抱闸开关断开； |
| [9]-[10] | CRC16校验 | 2u | DATA[0]~DATA[8]字节CRC16校验 |

---

### 抱闸控制开关输出控制；【命令码:0x2E】

#### 1. 主控制器(上位机)发送给从机(下位机)
| 序号 | 字段名称 | 类型 | 内容说明(数据) |
| :---: | :--- | :---: | :--- |
| [0] | 协议头 | 1u | 0xAE |
| [1] | 包序号 | 1u | 0x00~0xFF |
| [2] | 设备地址 | 1u | 0x01~0xFE |
| [3] | 命令码 | 1u | **0x2E** |
| [4] | 数据包长度 | 1u | 0x01 |
| [5] | 操作类型 | 1u | 0x00: 开关断开 0x01: 开关闭合 0xFF: 读取状态 |
| [6]-[7] | CRC16校验 | 2u | DATA[0]~DATA[5]字节CRC16校验 |

#### 2. 从机(下位机)应答主控制器(上位机)
| 序号 | 字段名称 | 类型 | 内容说明(数据) |
| :---: | :--- | :---: | :--- |
| [0] | 协议头 | 1u | 0xAC |
| [1] | 包序号 | 1u | 0x00~0xFF |
| [2] | 设备地址 | 1u | 0x01~0xFE |
| [3] | 命令码 | 1u | **0x2E** |
| [4] | 数据包长度 | 1u | 0x01 |
| [5] | 操作类型 | 1u | 0x00: 开关断开 0x01: 开关闭合 |
| [6]-[7] | CRC16校验 | 2u | DATA[0]~DATA[5]字节CRC16校验 |

---

### 电机失能 OFF；【命令码:0x2F】

#### 1. 主控制器(上位机)发送给从机(下位机)
| 序号 | 字段名称 | 类型 | 内容说明(数据) |
| :---: | :--- | :---: | :--- |
| [0] | 协议头 | 1u | 0xAE |
| [1] | 包序号 | 1u | 0x00~0xFF |
| [2] | 设备地址 | 1u | 0x01~0xFE |
| [3] | 命令码 | 1u | **0x2F** |
| [4] | 数据包长度 | 1u | 0x00 |
| [5]-[6] | CRC16校验 | 2u | DATA[0]~DATA[4]字节CRC16校验 |

#### 2. 从机(下位机)应答主控制器(上位机)
除了应答的命令码不同外，从机应答主机的内容与0x0B命令的内容一致；

---

## 运控模式：MIT 类型协议控制方式

为兼容不同规格的电机，协议内容支持根据当前电机的实际参数或使用需求，配置位置、速度和力矩的最大值。
需要注意的是，当前运控模式协议中，位置、速度和力矩的单位与前文有所不同：
1.  **位置单位**：弧度 (rad)，其中 2π rad 对应 360°；
2.  **速度单位**：弧度每秒 (rad/s)，其中 2π rad/s 对应 60 转/分 (rpm)；
3.  **力矩单位**：牛顿·米 (N·m)，需通过上位机正确配置电机力矩常数；

---

### 读取和配置 MIT 运动控制参数，断电保存；【命令码:0x30】

#### 1. 主控制器(上位机)发送给从机(下位机)
| 序号 | 字段名称 | 类型 | 内容说明(数据) |
| :---: | :--- | :---: | :--- |
| [0] | 协议头 | 1u | 0xAE |
| [1] | 包序号 | 1u | 0x00~0xFF |
| [2] | 设备地址 | 1u | 0x01~0xFE |
| [3] | 命令码 | 1u | **0x30** |
| [4] | 数据包长度 | 1u | **[0x00，读取参数]**、**[0x0A，配置参数]** |
| [5]-[6] | Pos_Max | 2u | 配置运控模式位置最大值，单位0.1rad；默认为95.5rad |
| [7]-[8] | Vel_Max | 2u | 配置运控模式速度最大值，单位0.01rad/s；默认为45rad/s |
| [9]-[10] | T_Max | 2u | 配置运控模式力矩最大值，单位0.01N·m；默认为18N·m； |
| [11]-[12]| Pos_KP_Max | 2u | 配置运控模式位置KP最大值，默认值为500，最大可配置到1000； |
| [13]-[14]| Vel_KD_Max | 2u | 配置运控模式速度KD最大值，默认值为5，最大可配置到100； |
| [15]-[16]| CRC16校验 | 2u | DATA[0]~DATA[14]字节CRC16校验 |

#### 2. 从机(下位机)应答主控制器(上位机)
| 序号 | 字段名称 | 类型 | 内容说明(数据) |
| :---: | :--- | :---: | :--- |
| [0] | 协议头 | 1u | 0xAC |
| [1] | 包序号 | 1u | 0x00~0xFF |
| [2] | 设备地址 | 1u | 0x01~0xFE |
| [3] | 命令码 | 1u | **0x30** |
| [4] | 数据包长度 | 1u | 0x0A |
| [5]-[6] | Pos_Max | 2u | 配置运控模式位置最大值，单位0.1rad； |
| [7]-[8] | Vel_Max | 2u | 配置运控模式速度最大值，单位0.01rad/s； |
| [9]-[10] | T_Max | 2u | 配置运控模式力矩最大值，单位0.01N·m； |
| [11]-[12]| Pos_KP_Max | 2u | 配置运控模式位置KP最大值，默认值为500，最大可配置到1000； |
| [13]-[14]| Vel_KD_Max | 2u | 配置运控模式速度KD最大值，默认值为5，最大可配置到100； |
| [15]-[16]| CRC16校验 | 2u | DATA[0]~DATA[14]字节CRC16校验 |

---

### 读取运控模式下的实时位置、速度、力矩和状态信息；【命令码:0x31】

#### 1. 主控制器(上位机)发送给从机(下位机)
| 序号 | 字段名称 | 类型 | 内容说明(数据) |
| :---: | :--- | :---: | :--- |
| [0] | 协议头 | 1u | 0xAE |
| [1] | 包序号 | 1u | 0x00~0xFF |
| [2] | 设备地址 | 1u | 0x01~0xFE |
| [3] | 命令码 | 1u | **0x31** |
| [4] | 数据包长度 | 1u | 0x00 |
| [5]-[6] | CRC16校验 | 2u | DATA[0]~DATA[4]字节CRC16校验 |

#### 2. 从机(下位机)应答主控制器(上位机)
| 序号 | 字段名称 | 类型 | 内容说明(数据) |
| :---: | :--- | :---: | :--- |
| [0] | 协议头 | 1u | 0xAC |
| [1] | 包序号 | 1u | 0x00~0xFF |
| [2] | 设备地址 | 1u | 0x01~0xFE |
| [3] | 命令码 | 1u | **0x31** |
| [4] | 数据包长度 | 1u | 0x09 |
| [5]-[6] | 机械位置 | 16bit | [5]为高8位，[6]为低8位；[0~65535]对应 (-Pos_Max ~ Pos_Max)； |
| [7]-[8] | 机械速度 | 12bit | [7]为高8位，[8]-Bit[7:4]为低4位；[0~4095]对应 (-Vel_Max ~ Vel_Max)； |
| [8]-[9] | 力矩 | 12bit | [8]-Bit[3:0]为高4位，[9]为低8位；[0~4095]对应 (-T_Max ~ T_Max)； |
| [10] | 状态信息 | 1u | [Bit0]: 为1表示处于运控模式；<br>[Bit1]: 为1表示系统有故障；<br>[Bit2~7]: 预留 |
| [11] | 工作温度 | 1u | 单位 ℃； |
| [12]-[13]| 预留 | 2u | 预留区域，默认0； |
| [14]-[15]| CRC16校验 | 2u | DATA[0]~DATA[13]字节CRC16校验 |

---

### 运控模式控制命令；【命令码:0x32】

#### 1. 主控制器(上位机)发送给从机(下位机)
| 序号 | 字段名称 | 类型 | 内容说明(数据) |
| :---: | :--- | :---: | :--- |
| [0] | 协议头 | 1u | 0xAE |
| [1] | 包序号 | 1u | 0x00~0xFF |
| [2] | 设备地址 | 1u | 0x01~0xFE |
| [3] | 命令码 | 1u | **0x32** |
| [4] | 数据包长度 | 1u | 0x08 |
| [5]-[6] | 目标位置 | 16bit | [5]为高8位，[6]为低8位；[0~65535]对应 (-Pos_Max ~ Pos_Max)； |
| [7]-[8] | 目标速度 | 12bit | [7]为高8位，[8]-Bit[7:4]为低4位；[0~4095]对应 (-Vel_Max ~ Vel_Max)； |
| [8]-[9] | 位置增益Kp值| 12bit | [8]-Bit[3:0]为高4位，[9]为低8位；[0~4095]对应 [0~Pos_KP_Max]； |
| [10]-[11]| 速度增益Kd值| 12bit | [10]为高8位，[11]-Bit[7:4]为低4位；[0~4095]对应 [0~Vel_KD_Max]； |
| [11]-[12]| 目标力矩 | 12bit | [11]-Bit[3:0]为高4位，[12]为低8位；[0~4095]对应 (-T_Max ~ T_Max)； |
| [13]-[14]| CRC16校验 | 2u | DATA[0]~DATA[12]字节CRC16校验 |

#### 2. 从机（下位机）应答主控制器（上位机）
除了应答的命令码不同外，从机应答主机的内容与0x31命令的内容一致；

---

## 自定义通信协议通信示例

### [0x0B 命令] - 读取单圈绝对值角度、多圈绝对值角度、速度、Q轴电流等实时信息；
假设从机设备地址为 1，通信数据帧如下：

**主控制器发送数据帧 (Hex):** （数据包长度为0，数据字段为空）
```
AE 00 01 0B 00 9B 28
```

**从机应答数据帧 (Hex):**
```
AC 00 01 0B 16 27 39 27 39 19 00 1E C8 00 00 19 00 00 00 94 0C 04 00 24 03 01 00 3B DD
```
*(标注：①: `27 39`，②: `27 39 19 00`，③: `1E C8 00 00`，④: `19 00 00 00`，⑤: `94 0C`，⑥: `04 00`，⑦: `24`，⑧: `03`，⑨: `01`，⑩: `00`)*

**根据 0x0B 协议内容解析从机应答数据字段：**
| 序号 | 字段名称 | 16进制(Hex) | 10进制(Dec) | 对应参数值/含义 |
| :---: | :--- | :--- | :--- | :--- |
| ① | 单圈绝对值角度 | `0x3927` | 14631 | 14631 * (360/16384) = 321.48° |
| ② | 多圈绝对值角度 | `0x00193927` | 1653031 | 1653031 * (360/16384) = 36321.48° |
| ③ | 机械速度 | `0x0000C81E` | 51230 | 51230 * 0.01 = 512.3rpm |
| ④ | Q轴电流 | `0x00000019` | 25 | 25 * 0.001 = 0.025A |
| ⑤ | 母线电压 | `0x0C94` | 3220 | 3220 * 0.01 = 32.2V |
| ⑥ | 母线电流 | `0x0004` | 4 | 4 * 0.01 = 0.04A |
| ⑦ | 工作温度 | `0x24` | 36 | 36℃ |
| ⑧ | 运行状态 | `0x03` | 3 | 速度控制模式 |
| ⑨ | 电机状态 | `0x01` | 1 | 使能 |
| ⑩ | 故障码 | `0x00` | 0 | 无故障 |

---

### [0x0F 命令] - 清除故障；
假设从机地址为 1，通信数据帧如下：

**主控制器发送数据帧 (Hex):** （数据包长度为0，数据字段为空）
```
AE 00 01 0F 00 99 E8
```

**从机应答数据帧 (Hex):**
```
AC 00 01 0F 01 00 28 18
```
*(标注 ①: `00`)*

**根据 0x0F 协议内容解析主控制器接收数据字段：**
*   **① 故障码**: `0x00`。表示没有故障。

---

### [0x20 命令] - Q轴电流控制；
目标Q轴电流 1A；假设从机地址为 1，通信数据帧如下：

**主控制器发送数据帧 (Hex):** （数据包长度为0x08）
```
AE 00 01 20 08 E8 03 00 00 00 00 00 00 CB 7C
```
*(标注 ①: `E8 03 00 00`，②: `00 00 00 00`)*

**从机应答数据帧 (Hex):** （应答内容格式与 0x0B 命令一致）
```
AC 00 01 20 16 27 39 27 39 19 00 1E C8 00 00 19 00 00 00 94 0C 04 00 24 03 10 00 AD F3
```

**根据 0x20 协议内容解析主控制器发送数据字段：**
*   **① Q轴电流**: `0x000003E8` (10进制: 1000) -> Q轴电流 = 1000 * 0.001 = 1A
*   **② 电流斜率**: `0x00000000` (10进制: 0) -> Q轴电流斜率 0，最大斜率

---

### [0x21 命令] - 速度控制；
目标速度 100rpm，假设从机设备地址为 1，通信数据帧如下：

**主控制器发送数据帧 (Hex):** （数据包长度为0x08）
```
AE 00 01 21 08 10 27 00 00 00 00 00 00 F0 59
```
*(标注 ①: `10 27 00 00`，②: `00 00 00 00`)*

**从机应答数据帧 (Hex):** （应答内容格式与 0x0B 命令一致）
```
AC 00 01 21 16 27 39 27 39 19 00 1E C8 00 00 19 00 00 00 94 0C 04 00 24 03 10 00 F0 66
```

**根据 0x21 协议内容解析主控制器发送数据字段：**
*   **① 速度**: `0x00002710` (10进制: 10000) -> 速度 = 10000 * 0.01 = 100rpm
*   **② 加速度**: `0x00000000` (10进制: 0) -> 加速度 0，最大加速度

---

### [0x22 命令] - 绝对值位置控制；
目标位置 16384count；假设从机设备地址为 1，通信数据帧如下：

**主控制器发送数据帧 (Hex):** （数据包长度为0x04）
```
AE 00 01 22 04 00 40 00 00 58 C1
```
*(标注 ①: `00 40 00 00`)*

**从机应答数据帧 (Hex):** （应答内容格式与 0x0B 命令一致）
```
AC 00 01 22 16 27 39 27 39 19 00 1E C8 00 00 19 00 00 00 94 0C 04 00 24 03 10 00 14 99
```

**根据 0x22 协议内容解析主控制器发送数据字段：**
*   **① 绝对值位置**: `0x00004000` (10进制: 16384) -> 16384 * (360/16384) = 360°，电机旋转到多圈绝对值位置 16384count 位置；

---

### [0x23 命令] - 相对位置控制；
转动角度 90°；假设从机设备地址为 1，通信数据帧如下：

**主控制器发送数据帧 (Hex):** （数据包长度为0x04）
```
AE 00 01 23 04 00 10 00 00 59 01
```
*(标注 ①: `00 10 00 00`)*

**从机应答数据帧 (Hex):** （应答内容格式与 0x0B 命令一致）
```
AC 00 01 23 16 27 39 27 39 19 00 1E C8 00 00 19 00 00 00 94 0C 04 00 24 03 10 00 49 0C
```

**根据 0x23 协议内容解析主控制器发送数据字段：**
*   **① 相对位置**: `0x00001000` (10进制: 4096) -> 4096 * (360/16384) = 90°，电机基于当前位置正方向旋转 90 度；

---

### [0x26 命令] - 梯形曲线绝对位置控制；
转动角度 90°；假设从机设备地址为 1，通信数据帧如下：

**主控制器发送数据帧 (Hex):** （数据包长度为0x11）
```
AE 00 01 26 11 00 00 10 00 00 E8 03 00 00 E8 03 00 00 E8 03 00 00 70 75
```
*(标注 ①: `00`，②: `00 10 00 00`，③: `E8 03 00 00`，④: `E8 03 00 00`，⑤: `E8 03 00 00`)*

**从机应答数据帧 (Hex):** （应答内容格式与 0x0B 命令一致）
```
AC 00 01 26 16 27 39 27 39 19 00 1E C8 00 00 19 00 00 00 94 0C 04 00 24 03 10 00 66 4C
```

**根据 0x26 协议内容解析主控制器发送数据字段：**
*   **① 控制模式**: `0x00` -> 绝对值控制
*   **② 目标位置**: `0x00001000` (10进制: 4096) -> 4096 * (360/16384) = 90°，电机旋转到多圈绝对值位置 4096count 位置；
*   **③ 最大速度**: `0x000003E8` (10进制: 1000) -> 1000 * 0.01 = 10rpm，电机最大旋转速度 10rpm
*   **④ 最大速度**: `0x000003E8` (10进制: 1000) -> 1000 * 0.01 = 10rpm/s，电机最大加速度 10rpm/s
*   **⑤ 最大减速度**: `0x000003E8` (10进制: 1000) -> 1000 * 0.01 = 10rpm/s，电机最大减速度 10rpm/s

---

### [0x27 命令] - 位置滤波控制；
转动角度 90°；假设从机设备地址为 1，通信数据帧如下：

**主控制器发送数据帧 (Hex):** （数据包长度为0x09）
```
AE 00 01 27 09 00 00 10 00 00 E8 03 00 00 4C 56
```
*(标注 ①: `00`，②: `00 10 00 00`，③: `E8 03 00 00`)*

**从机应答数据帧 (Hex):** （应答内容格式与 0x0B 命令一致）
```
AC 00 01 27 16 27 39 27 39 19 00 1E C8 00 00 19 00 00 00 94 0C 04 00 24 03 10 00 3B D9
```

**根据 0x27 协议内容解析主控制器发送数据字段：**
*   **① 控制模式**: `0x00` -> 绝对值控制
*   **② 目标位置**: `0x00001000` (10进制: 4096) -> 4096 * (360/16384) = 90°，电机旋转到多圈绝对值位置 4096count 位置；
*   **③ 最大速度**: `0x000003E8` (10进制: 1000) -> 1000 * 0.01 = 10rpm，电机最大旋转速度 10rpm

---

### [0x2F 命令] - 电机失能；
假设从机地址为 1，通信数据帧如下：

**主控制器发送数据帧 (Hex):** （数据包长度为0，数据字段为空）
```
AE 00 01 2F 00 80 28
```

**从机应答数据帧 (Hex):** （应答内容格式与 0x0B 命令一致）
```
AC 00 01 2F 16 27 39 27 39 19 00 1E C8 00 00 19 00 00 00 94 0C 04 00 24 03 10 00 DC 33
```

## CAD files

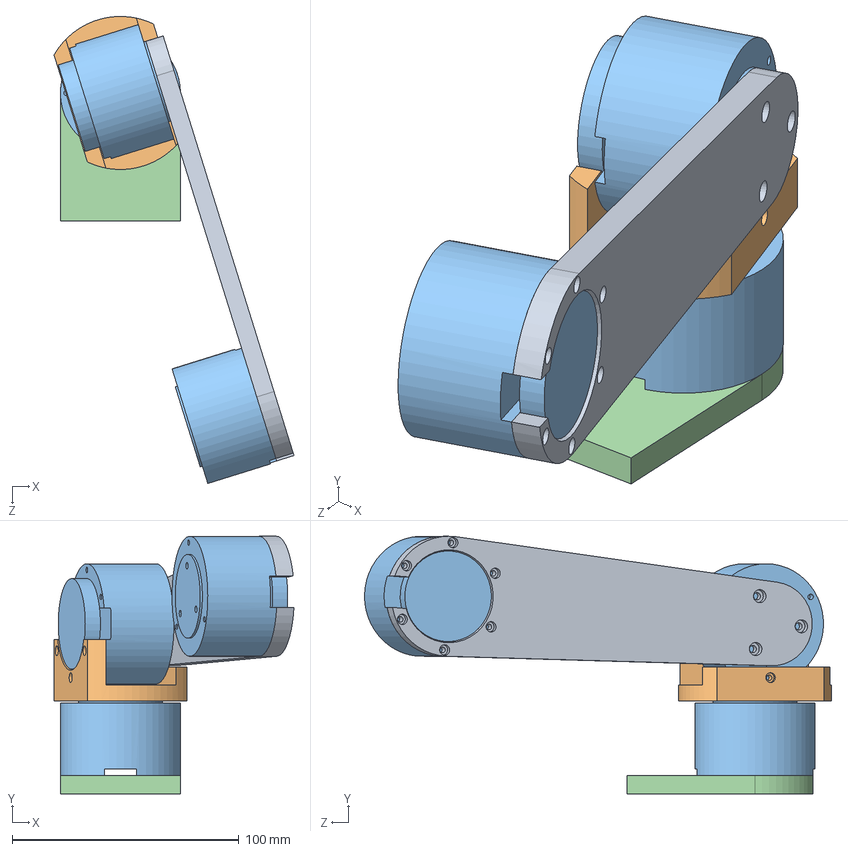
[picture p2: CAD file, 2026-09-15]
模型/装配.SLDASM
105.9 x 113.7 x 206.1 mm
底座
电机 x 3
肩关节
大臂

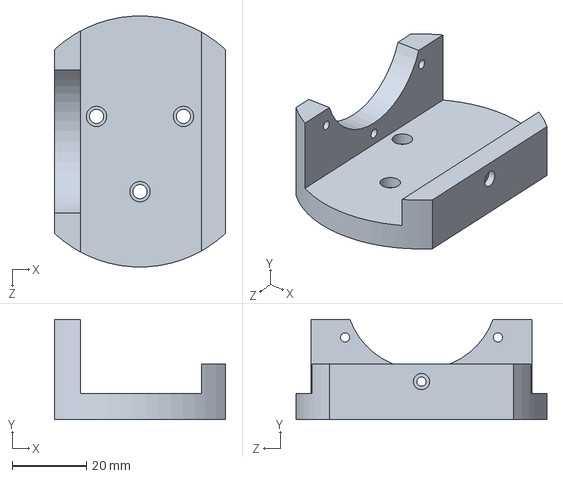
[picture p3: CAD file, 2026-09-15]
模型/肩关节.SLDPRT
46.0 x 27.0 x 67.5 mm

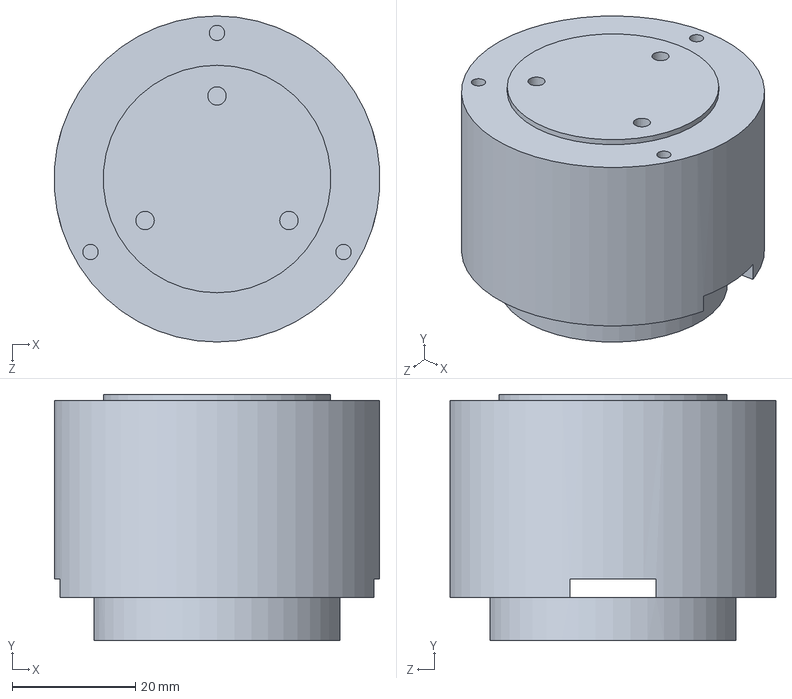
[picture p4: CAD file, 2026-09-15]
模型/电机.SLDPRT
52.9 x 40.0 x 53.0 mm

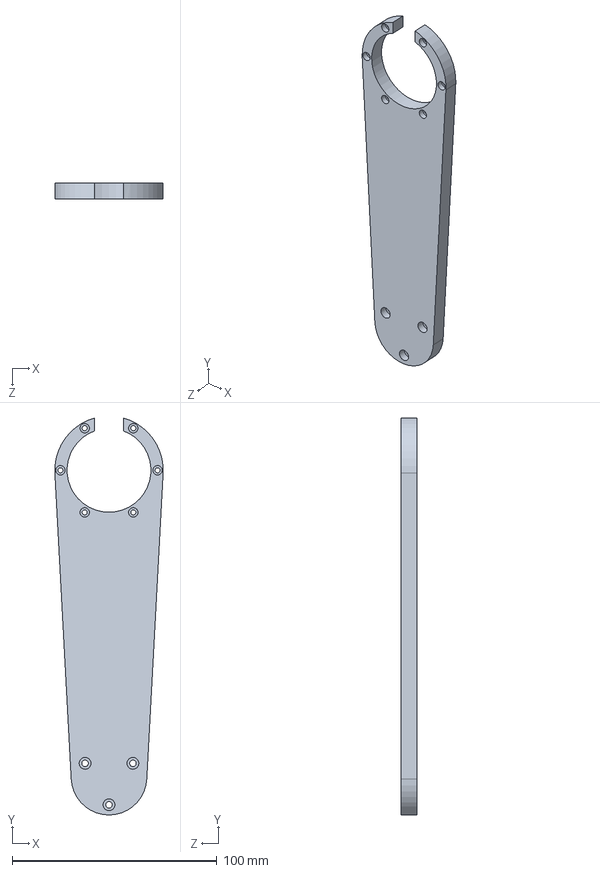
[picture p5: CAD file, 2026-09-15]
模型/大臂.SLDPRT
52.9 x 194.1 x 8.00 mm

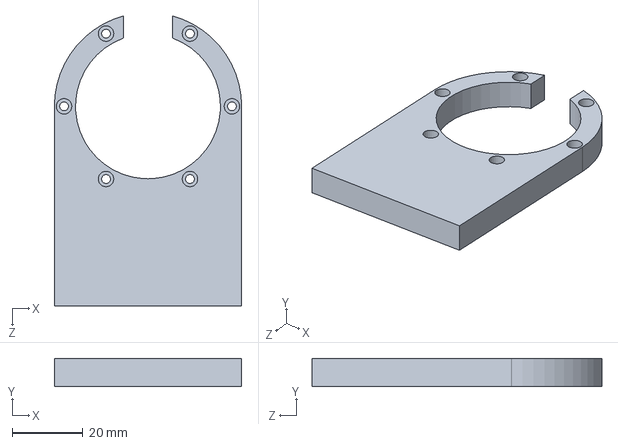
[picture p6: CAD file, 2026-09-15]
模型/底座.SLDPRT
53.0 x 8.00 x 82.1 mm

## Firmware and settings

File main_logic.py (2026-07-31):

#!/usr/bin/python3
"""机械臂主逻辑 — 启动流程 + 控制台绝对笛卡尔控制 (执行器中心坐标)

启动后:
  1. 机械臂移动到待机位置 (实际笛卡尔坐标 X=-9, Y=0, Z=+80 mm)
  2. 向 ESP32 发送 red_on, 红灯亮起, 并保持待机
  3. 开启摄像头目标识别 (YOLO, 见 infer.py): 检测到目标后打印中心点
     像素坐标一次, 并将 ESP32 灯光切换为绿色常亮
  4. 控制台输入指令移动机械臂 (坐标对应执行器中心, 含 TOOL_OFFSET 偏移):
       <Xmm> <Ymm> [Zmm]   绝对笛卡尔坐标, Z 缺省保持当前
       n <u> <v> [Zmm]     摄像头像素坐标, 线性变换为执行器坐标后移动
       action             下降到 Z_DOWN → 继电器吸合 → Z 回升到 0 (抓取)
       put                下降到 Z_DOWN → 继电器释放 → Z 回升到 0 (放下)
       trans <u> <v> [角度]  搬运: 抓取点 → 抓取 → 放置点 → [舵机旋转角度] → 放下
                       (角度可选, 放置点放下前旋转, 正=逆时针, 如: trans 123 85 )
       transport <u1> <v1> <u2> <v2> [角度]  同 trans, 但放置点显式指定
                       (V2 仍自动 -330, 如: transport 200 200 300 300 +60 → 放置点 300, -30)
       r <角度>           舵机相对转动, 正=逆时针 (如: r 50, r -30)
       read               跑一遍装配流程 (等价于 infer.py 按 R 键),
                          输出 #N(原始坐标)-(爆炸图坐标, 旋转角) 碎片数据
       t1 ~ t4            read 后把第 N 个碎片数据传入 transport 执行:
                          抓取点=原始坐标, 放置点=爆炸图坐标 (V2 仍自动 -330),
                          角度=旋转角
       例: 90 0 → 执行器中心移动到 (X=90, Y=0)
       home / standby      回到待机位置 (X=-9, Y=0, Z=80)
       ready              移动到准备位置 (执行器 X=175.3, Y=-35.3, Z=47.6)
       status              显示当前位置     ? / help → 本帮助

所有机械臂运动学/控制 (极坐标换算、IK、执行器偏移、目标状态跟踪) 均在
arm_driver.CartesianArm 中实现, 本文件只负责启动流程与指令解析.

用法:
    python3 main_logic.py                  # 自动检测 ESP32 串口
    python3 main_logic.py --esp-port /dev/ttyUSB0
    python3 main_logic.py --no             # 调试模式: 不运行任何视觉功能
"""

import argparse
import select
import sys
import time

from arm_driver import CartesianArm, Esp32Cmd, detect_esp32_port
from servo_driver import (FeetechSTSServo, SERVO_PORT,
                          SERVO_STEP_PER_DEG, SERVO_SPEED)

# ── 待机位置 (实际笛卡尔坐标, mm) ───────────────────────────────────────────
STANDBY_X = -9.0
STANDBY_Y = 0.0
STANDBY_Z = 60.0

STANDBY_SPEED_RPM = 10.0   # 待机移动转速 (rpm)

# ── ready 准备位置 (执行器中心坐标, mm) ─────────────────────────────────────
READY_X = 175.3
READY_Y = -35.3
READY_Z = 47.6
READY_SPEED_RPM = 10.0   # 移动到 ready 位置的转速 (rpm)

# ── 基座旋转 → 舵机反向补偿 ────────────────────────────────────────────────
# 电机1 (基座) 旋转 Δ° 后, 舵机自动反向旋转补偿, 抵消基座转动对工具姿态的
# 影响 (保持抓取物方向不变). 方向推导: 基座角增大 = 从上方 (摄像头视角) 看
# 顺时针 (FK 镜像约定 x=-r·cosθ1, y=r·sinθ1, 相机 +x 右 / +y 上), 而舵机
# 正 = 逆时针, 故补偿量 = +Δ 即满足 "基座顺时针 Δ° → 舵机逆时针 Δ°".
# 若实测补偿方向相反, 将该值改为 -1.
SERVO_BASE_COMP_GAIN = -1.0

# ── action 动作序列参数 (执行器中心 Z, mm) ────────────────────────────────
ACTION_Z_DOWN = -36.0   # ① 下降到该高度
ACTION_Z_UP   =   0.0   # ④ 动作结束后 Z 回升到该高度
ACTION_WAIT_DOWN = 1.0  # ② 到位后等待 (s)
ACTION_WAIT_MAG  = 0.5  # ③ 继电器吸合后等待 (s)
ACTION_SPEED_RPM = 2.0   # ⑤ 动作移动转速 (rpm, 临时限速: 缓慢下降测试用)
ACTION_ID3_DELAY = 0.5   # ④ 回升段: 电机3 (ID3) 延时旋转 (s), 在 ID2 之后动
ACTION_ID4_DELAY = 0.5   # ④ 回升段: 电机4 (ID4) 延时旋转 (s), 在 ID3 之后动

# ── trans 搬运序列参数 (相机像素坐标, px) ─────────────────────────────────
TRANS_V_OFFSET = -380.0  # 放置点 V = 抓取点 V - 400 
TRANS_WAIT     = 0.5     # 各步骤之间的等待时间 (s)
TRANS_STEP_NUMS = ("①", "②", "③", "④", "⑤", "⑥")   # 序列步骤圈号 (最多 6 步)


class MainLogic:
    """机械臂主逻辑 — 启动流程 + 控制台绝对笛卡尔控制 (执行器中心)."""

    def __init__(self, esp_port=None, no_vision=False):
        self.arm = CartesianArm()          # 机械臂 + 笛卡尔控制层 (含手腕水平参考)
        # 基座旋转 → 舵机反向补偿 (保持工具姿态; 舵机未连接时内部自动跳过)
        self.arm.on_base_rotate = self._compensate_base_rotation
        self.no_vision = no_vision         # 调试模式: 跳过一切视觉功能
        self._model = None                 # YOLO 模型缓存 (detect_target 与 read 共用)
        self._fragments = None             # 最近一次 read 的碎片数据 (t1~tN 指令用)
        esp_port = esp_port or detect_esp32_port()
        self.esp = None
        if esp_port:
            try:
                self.esp = Esp32Cmd(esp_port)
                print(f"ESP32 已连接: {esp_port}")
            except Exception as e:
                print(f"⚠ ESP32 连接失败: {e} — 红灯指令不可用")
        else:
            print("⚠ 未检测到 ESP32 — 红灯指令不可用 (可用 --esp-port 指定)")

        # ── 舵机 (Feetech STS/SCS) ──
        self.servo = None
        try:
            self.servo = FeetechSTSServo(SERVO_PORT)
            if not (self.servo.is_open and self.servo.is_online()):
                print("⚠ 舵机未应答 — r 指令不可用")
                self.servo.close()
                self.servo = None
            else:
                pos, _ = self.servo.read_position()
                print(f"舵机已连接: {SERVO_PORT} "
                      f"(位置 {pos} ≈ {pos / SERVO_STEP_PER_DEG:.1f}°)")
        except Exception as e:
            print(f"⚠ 舵机连接失败: {e} — r 指令不可用")
            self.servo = None

    # ── 基座旋转补偿 ──

    def _compensate_base_rotation(self, delta_deg):
        """基座 (ID1) 旋转后的舵机反向补偿 (arm.on_base_rotate 回调).

        电机1 旋转 Δ° 时, 舵机反向旋转 Δ × SERVO_BASE_COMP_GAIN
        (舵机正 = 逆时针), 保持工具/碎片绝对姿态不变.
        Δ 的符号约定: 基座角增大 = 从上方看顺时针.
        舵机未连接时警告并跳过, 不影响机械臂移动.
        """
        if not self.servo:
            print(f"  ⚠ 基座旋转 {delta_deg:+.1f}°, 舵机未连接 — 跳过旋转补偿")
            return
        comp_deg = delta_deg * SERVO_BASE_COMP_GAIN
        print(f"  [补偿] 基座 {delta_deg:+.1f}° → 舵机反向 {comp_deg:+.1f}°")
        new_pos = self.servo.move_relative_deg(comp_deg,
                                               target_speed=SERVO_SPEED)
        if new_pos is None:
            print("  ⚠ 舵机补偿失败 (读取当前位置失败)")
        else:
            print(f"  ✓ 舵机补偿 → 位置 {new_pos} "
                  f"({new_pos / SERVO_STEP_PER_DEG:.1f}°)")

    # ── 启动流程 ──

    def startup(self):
        """① 移动到待机位置  ② 红灯亮起."""
        print("── 第一步: 启动流程 ──")
        self.arm.go_standby(STANDBY_X, STANDBY_Y, STANDBY_Z,
                            speed_rpm=STANDBY_SPEED_RPM)
        if self.esp:
            self.esp.red_on()
        else:
            print("⚠ ESP32 未连接, 跳过 red_on")

    def detect_target(self):
        """目标识别: 开启摄像头等待检测, 打印中心点坐标一次, 灯光切换绿色常亮."""
        print("── 目标识别 ──")
        try:
            import infer
        except Exception as e:
            print(f"⚠ 无法加载目标识别模块: {e}")
            return
        try:
            model = self._get_model()
            cap = infer.open_camera()
            if cap is None:
                print("⚠ 无法打开摄像头, 跳过目标识别")
                return
            try:
                res = infer.detect_first_target(model, cap)
            finally:
                cap.release()
            if res is None:
                print("⚠ 未检测到目标")
                return
            cx, cy, cls = res
            print(f"  ✓ 检测到目标 [{cls}], 中心点像素坐标 (u={cx}, v={cy})")
            if self.esp:
                self.esp.red_off()
                self.esp.green_on()
                print("  ✓ 灯光已切换为绿色常亮")
            else:
                print("⚠ ESP32 未连接, 跳过绿灯")
        except KeyboardInterrupt:
            print("⚠ 目标识别被中断, 跳过")
        except Exception as e:
            print(f"⚠ 目标识别失败: {e}")

    def _get_model(self):
        """惰性加载并缓存 YOLO 模型 (detect_target 与 read 共用)."""
        if self._model is None:
            import infer
            self._model = infer.load_model()
        return self._model

    def _run_read(self):
        """read: 跑一遍完整装配流程 (等价于 infer.py 按 R 键) 并输出碎片数据.

        输出格式: #N(原始坐标)-(爆炸图坐标, 旋转角)
        原始坐标 = 摄像头画面中碎片多边形几何中心 (像素);
        爆炸图坐标 = 爆炸图画布中该碎片位置几何中心 (像素);
        旋转角 = 拼接对齐相对原始位姿的旋转角 (°, 顺时针为正、逆时针为负,
                 已在 reassemble 计算源头取反, 为舵机方向约定,
                 可直接用于 trans 角度).
        """
        try:
            import infer
        except Exception as e:
            print(f"⚠ 无法加载目标识别模块: {e}")
            return
        try:
            model = self._get_model()
        except Exception as e:
            print(f"⚠ 模型加载失败: {e}")
            return
        cap = infer.open_camera()
        if cap is None:
            print("⚠ 无法打开摄像头, 跳过 read")
            return
        try:
            data = infer.run_read_pipeline(model, cap)
        finally:
            cap.release()
        if data is None:
            return
        self._fragments = data
        print("── 碎片数据: #N(原始坐标)-(爆炸图坐标, 旋转角) ──")
        for d in data:
            ox, oy = d["orig"]
            ex, ey = d["exploded"]
            print(f"  #{d['idx'] + 1}({ox}, {oy})-({ex}, {ey}, {d['rot_deg']:+.1f}°)")
        print(f"  (输入 t1 ~ t{len(data)} 将对应碎片数据传入 transport 执行搬运)")

    def run(self):
        """主逻辑入口 — 启动 → 目标识别 → 控制台控制循环."""
        self.startup()

        print(f"\n✓ 启动完成: 机械臂待机 (X={STANDBY_X:.0f}, Y={STANDBY_Y:.0f}, "
              f"Z={STANDBY_Z:.0f}), 红灯亮")
        if self.no_vision:
            print("⚠ 调试模式 (--no): 跳过目标识别, 视觉功能关闭")
        else:
            self.detect_target()

        self._print_usage()
        print("按 Ctrl+C 退出")

        try:
            while True:
                if sys.stdin in select.select([sys.stdin], [], [], 0)[0]:
                    line = sys.stdin.readline()
                    if line == "":            # EOF (Ctrl+D)
                        print("\n输入结束, 退出")
                        break
                    line = line.strip()
                    if not line:
                        continue
                    if line in ("status", "s"):
                        self._show_status()
                    else:
                        self._apply_command(line)
                else:
                    time.sleep(0.05)
        except KeyboardInterrupt:
            print("\n退出")

    # ── 控制台解析 ──

    def _print_usage(self):
        """打印控制台指令说明."""
        print("控制台指令: <Xmm> <Ymm> [Zmm]   (执行器中心绝对坐标, Z 缺省保持当前)")
        print("           n <u> <v> [Zmm]     (摄像头像素坐标, Z 缺省保持当前)")
        print("           home / standby     → 回到待机位置 (X=-9, Y=0, Z=80)")
        print(f"           ready / rd         → 移动到准备位置 (执行器 X={READY_X:.0f}, Y={READY_Y:.0f}, Z={READY_Z:.0f})")
        print(f"           action / act       → 下降到 Z={ACTION_Z_DOWN:.0f} → 继电器吸合 → Z 回升到 {ACTION_Z_UP:.0f} (抓取)")
        print(f"           put                → 下降到 Z={ACTION_Z_DOWN:.0f} → 继电器释放 → Z 回升到 {ACTION_Z_UP:.0f} (放下)")
        print(f"           trans <u> <v> [角度] → 搬运: 抓取点 n <u> <v> 0 → 抓取 → 放置点 n <u> <v{TRANS_V_OFFSET:+.0f}> 0 → [舵机旋转角度] → 放下")
        print("                       角度可选 (放置点放下前旋转, 放下后反向回旋防缠绕, 正=逆时针), 例如: trans 300 200 +60")
        print(f"           transport <u1> <v1> <u2> <v2> [角度] → 同 trans, 但放置点显式指定 (V2 仍 {TRANS_V_OFFSET:+.0f})")
        print("                       例如: transport 200 200 300 300 +60 → 放置点 (300, -30)")
        print("           r <角度>            → 舵机相对转动, 正=逆时针 (如: r 50, r -30)")
        print("           read               → 跑一遍装配流程 (等价于 infer.py 按 R), 输出 #N(原始坐标)-(爆炸图坐标, 旋转角)")
        print("           t1 ~ t4            → 将 read 结果第 N 个碎片数据传入 transport 执行")
        print("                        (抓取点=原始坐标, 放置点=爆炸图坐标, V2 仍自动 -330, 角度=旋转角)")
        print("           status             → 显示当前位置     ? / help → 本帮助")
        print("  例: 90 0      → 移动到 (X=90,  Y=0)")
        print("      100 50 80 → 移动到 (X=100, Y=50, Z=80)")
        print("      n 123 85  → 相机像素 → 执行器坐标移动 (≈ X=90, Y=-8.4)")

    def _show_status(self):
        """显示当前实际关节角与执行器中心坐标."""
        joints, (x, y, z), (tx, ty, tz) = self.arm.status()
        print(f"  实际 ID1={joints[1]:+.1f}°  ID2={joints[2]:+.1f}°  "
              f"ID3={joints[3]:+.1f}°  ID4={joints[4]:+.1f}°")
        print(f"        腕部   X={x:+.1f}  Y={y:+.1f}  Z={z:+.1f} mm")
        print(f"        执行器 X={tx:+.1f}  Y={ty:+.1f}  Z={tz:+.1f} mm")

    def _run_ready(self):
        """ready: 移动到准备位置 (执行器中心 X/Y/Z, 常量 READY_*)."""
        print(f"── 移动至 ready 位置: 执行器 X={READY_X:+.1f}  "
              f"Y={READY_Y:+.1f}  Z={READY_Z:+.1f} mm "
              f"(转速 {READY_SPEED_RPM:.0f} rpm) ──")
        self.arm.move_tool_to(READY_X, READY_Y, READY_Z,
                              speed_rpm=READY_SPEED_RPM)

    def _run_action(self, mag_on=True):
        """抓取/放下序列: 当前位置 → 下降到 Z_DOWN → 等 1s → 继电器吸合/释放 → 等 0.5s → Z 回升到 0.

        mag_on=True  → 继电器吸合 (action 抓取); mag_on=False → 继电器释放 (put 放下).
        保持当前 X/Y 不变, 只改变执行器中心 Z 高度.
        """
        if not self.esp:
            print("  ⚠ ESP32 未连接, 无法控制继电器 — 动作中止")
            return
        *_, (tx, ty, tz) = self.arm.status()
        print(f"  [动作] 当前位置: 执行器 X={tx:+.1f}  Y={ty:+.1f}  Z={tz:+.1f} mm")
        print(f"  [动作] ① 下降到 Z={ACTION_Z_DOWN:.0f} mm "
              f"(转速 {ACTION_SPEED_RPM:.0f} rpm)")
        self.arm.move_tool_to(tx, ty, ACTION_Z_DOWN, speed_rpm=ACTION_SPEED_RPM)
        print(f"  [动作] ② 等待 {ACTION_WAIT_DOWN:.0f}s")
        time.sleep(ACTION_WAIT_DOWN)
        name = "吸合" if mag_on else "释放"
        cmd = "mag_high" if mag_on else "mag_low"
        print(f"  [动作] ③ 继电器{name} ({cmd})")
        if mag_on:
            self.esp.relay_on()
        else:
            self.esp.relay_off()
        time.sleep(ACTION_WAIT_MAG)
        print(f"  [动作] ④ Z 回升到 {ACTION_Z_UP:.0f} mm "
              f"(转速 {ACTION_SPEED_RPM:.0f} rpm, "
              f"电机3/4 分步延时 {ACTION_ID3_DELAY:.1f}s/{ACTION_ID4_DELAY:.1f}s)")
        self.arm.move_tool_to(tx, ty, ACTION_Z_UP, speed_rpm=ACTION_SPEED_RPM,
                              joint_delays={3: ACTION_ID3_DELAY,
                                            4: ACTION_ID4_DELAY})
        print(f"  ✓ {'抓取' if mag_on else '放下'}完成")

    def _run_trans(self, u, v, angle_deg=None, u_place=None, v_place=None):
        """trans / transport 搬运序列: 移动到抓取点 → 抓取 → 移动到放置点 → [舵机旋转] → 放下.

        u/v 为抓取点相机像素坐标; 放置点缺省取 (u, v + TRANS_V_OFFSET)
        (trans 行为). transport 变体显式指定放置点 (u_place, v_place),
        其 V 仍应用 TRANS_V_OFFSET 偏移 (实际位置 = v_place + TRANS_V_OFFSET),
        例如 transport 200 200 300 300 +60 → 放置点 (300, -30).
        各步骤之间等待 TRANS_WAIT 秒.

        angle_deg 非 None 时, 在移动到放置点后、放下前让舵机相对转动
        该角度 (在放置点旋转碎片, 正=逆时针), 例如 trans 300 200 +60.
        放下 (put) 完成后, 舵机再反向回旋相同度数, 防止线材缠绕.
        舵机未连接时警告并跳过旋转/回旋, 搬运流程继续.
        """
        u_place = u if u_place is None else u_place
        v_place = (v if v_place is None else v_place) + TRANS_V_OFFSET
        print(f"  [trans] ① 移动到抓取点: n {u:.0f} {v:.0f} 0")
        self.arm.move_camera_to(u, v, 0.0)
        time.sleep(TRANS_WAIT)
        print("  [trans] ② 抓取 (action)")
        self._run_action(mag_on=True)
        time.sleep(TRANS_WAIT)
        step = 2
        step += 1
        print(f"  [trans] {TRANS_STEP_NUMS[step - 1]} 移动到放置点: "
              f"n {u_place:.0f} {v_place:.0f} 0  (V{TRANS_V_OFFSET:+.0f})")
        self.arm.move_camera_to(u_place, v_place, 0.0)
        time.sleep(TRANS_WAIT)
        if angle_deg is not None:
            step += 1
            if not self.servo:
                print(f"  ⚠ 舵机未连接, 跳过旋转 {angle_deg:+.0f}°")
            else:
                print(f"  [trans] {TRANS_STEP_NUMS[step - 1]} 舵机旋转 "
                      f"{angle_deg:+.0f}° (放置点, 放下前旋转碎片)")
                new_pos = self.servo.move_relative_deg(
                    angle_deg, target_speed=SERVO_SPEED)
                if new_pos is None:
                    print("  ⚠ 读取舵机当前位置失败, 未旋转")
                else:
                    print(f"  ✓ 舵机 → 新位置 {new_pos} "
                          f"({new_pos / SERVO_STEP_PER_DEG:.1f}°)")
                    # 阻塞等待舵机到位 (替代固定延时, 到位才继续放下)
                    if self.servo.wait_for_arrival(new_pos):
                        print("  ✓ 舵机到位")
                    else:
                        print("  ⚠ 舵机旋转等待超时 — 继续放下")
        step += 1
        print(f"  [trans] {TRANS_STEP_NUMS[step - 1]} 放下 (put)")
        self._run_action(mag_on=False)
        if angle_deg is not None:
            step += 1
            if not self.servo:
                print(f"  ⚠ 舵机未连接, 跳过反向回旋 {angle_deg:+.0f}°")
            else:
                # 放下后反向回旋相同度数, 防止线材缠绕
                print(f"  [trans] {TRANS_STEP_NUMS[step - 1]} 舵机反向回旋 "
                      f"{angle_deg:+.0f}° (防止线材缠绕)")
                new_pos = self.servo.move_relative_deg(-angle_deg,
                                                       target_speed=SERVO_SPEED)
                if new_pos is None:
                    print("  ⚠ 读取舵机当前位置失败, 未回旋")
                else:
                    print(f"  ✓ 舵机 → 新位置 {new_pos} "
                          f"({new_pos / SERVO_STEP_PER_DEG:.1f}°)")
                    if self.servo.wait_for_arrival(new_pos):
                        print("  ✓ 舵机回旋到位")
                    else:
                        print("  ⚠ 舵机回旋等待超时")
        print("  ✓ trans 搬运完成")

    def _run_trans_by_fragment(self, n):
        """tN: 将最近一次 read 结果的第 N 个碎片数据传入 transport 执行.

        抓取点 = 原始坐标 (碎片当前在摄像头画面中的位置);
        放置点 = 爆炸图坐标 (V2 仍自动 -330, 实际放置 (ex, ey-330));
        角度   = 拼接对齐旋转角 (可直接作舵机旋转角).
        """
        if not self._fragments:
            print(f"  ⚠ 请先运行 read 获取碎片数据, 再使用 t{n}")
            return
        if n < 1 or n > len(self._fragments):
            print(f"  ⚠ 只有 {len(self._fragments)} 个碎片 (#1 ~ "
                  f"#{len(self._fragments)}), 没有 #{n}")
            return
        d = self._fragments[n - 1]
        ox, oy = d["orig"]
        ex, ey = d["exploded"]
        rot = d["rot_deg"]
        print(f"  [t{n}] 碎片 #{d['idx'] + 1}: 抓取 ({ox:.0f}, {oy:.0f}) → "
              f"放置 ({ex:.0f}, {ey:.0f}) 旋转 {rot:+.1f}°")
        self._run_trans(ox, oy, rot, ex, ey)

    def _apply_command(self, line):
        """解析控制台指令: 绝对笛卡尔 <Xmm> <Ymm> [Zmm] → move_tool_to."""
        parts = line.split()
        if parts[0] in ("?", "h", "help"):
            self._print_usage()
            return
        if parts[0] in ("home", "standby"):
            self.arm.go_home(STANDBY_X, STANDBY_Y, STANDBY_Z,
                             speed_rpm=STANDBY_SPEED_RPM)
            return
        if parts[0] in ("ready", "rd"):
            self._run_ready()
            return
        if parts[0] in ("action", "act"):
            self._run_action(mag_on=True)
            return
        if parts[0] in ("put", "place"):
            self._run_action(mag_on=False)
            return
        if parts[0] == "trans":
            try:
                vals = [float(p) for p in parts[1:]]
            except ValueError:
                print("  ⚠ 格式错误, 请输入: trans <u> <v> [角度]  例如: trans 123 85 或 trans 123 85 +60")
                return
            if len(vals) < 2:
                print("  ⚠ 至少需要 U 和 V: trans <u> <v> [角度]  例如: trans 123 85")
                return
            if len(vals) > 3:
                print("  ⚠ 参数过多, 最多 3 个: trans <u> <v> [角度]  例如: trans 123 85 +60")
                return
            angle = vals[2] if len(vals) > 2 else None
            self._run_trans(vals[0], vals[1], angle)
            return
        if parts[0] in ("transport", "transp"):
            try:
                vals = [float(p) for p in parts[1:]]
            except ValueError:
                print("  ⚠ 格式错误, 请输入: transport <u1> <v1> <u2> <v2> [角度]  例如: transport 200 200 300 300 +60")
                return
            if len(vals) < 4:
                print("  ⚠ 至少需要 4 个参数: transport <u1> <v1> <u2> <v2> [角度]  例如: transport 200 200 300 300 +60")
                return
            if len(vals) > 5:
                print("  ⚠ 参数过多, 最多 5 个: transport <u1> <v1> <u2> <v2> [角度]")
                return
            angle = vals[4] if len(vals) > 4 else None
            # 放置点 (u2, v2): V 仍自动 -330 → 实际移动到 (u2, v2-330)
            self._run_trans(vals[0], vals[1], angle, vals[2], vals[3])
            return
        if parts[0] == "read":
            self._run_read()
            return
        # tN (t1~t4): read 后把第 N 个碎片数据传入 transport 执行
        if (len(parts[0]) > 1 and parts[0][0] == "t"
                and parts[0][1:].isdigit()):
            self._run_trans_by_fragment(int(parts[0][1:]))
            return
        if parts[0] in ("r", "servo"):
            if not self.servo:
                print("  ⚠ 舵机未连接, r 指令不可用")
                return
            if len(parts) < 2:
                print("  ⚠ 请输入偏转角度, 例如: r 50 (逆时针 50°) 或 r -30")
                return
            try:
                delta_deg = float(parts[1])
            except ValueError:
                print("  ⚠ 角度格式错误, 例如: r 50 或 r -30")
                return
            new_pos = self.servo.move_relative_deg(delta_deg,
                                                   target_speed=SERVO_SPEED)
            if new_pos is None:
                print("  ⚠ 读取舵机当前位置失败, 未移动")
            else:
                print(f"  ✓ 舵机 {delta_deg:+.0f}° → "
                      f"新位置 {new_pos} ({new_pos / SERVO_STEP_PER_DEG:.1f}°)")
                # 阻塞等待舵机到位
                if self.servo.wait_for_arrival(new_pos):
                    print("  ✓ 舵机到位")
                else:
                    print("  ⚠ 舵机旋转等待超时")
            return
        if parts[0] in ("n", "cam"):
            try:
                vals = [float(p) for p in parts[1:]]
            except ValueError:
                print("  ⚠ 格式错误, 请输入: n <u> <v> [Zmm]  例如: n 123 85")
                return
            if len(vals) < 2:
                print("  ⚠ 至少需要 U 和 V: n <u> <v>  例如: n 123 85")
                return
            if len(vals) > 3:
                print("  ⚠ 参数过多, 最多 3 个: n <u> <v> [Zmm]")
                return
            u, v = vals[0], vals[1]
            z = vals[2] if len(vals) > 2 else None
            self.arm.move_camera_to(u, v, z)
            return
        try:
            vals = [float(p) for p in parts]
        except ValueError:
            print("  ⚠ 格式错误, 请输入: <Xmm> <Ymm> [Zmm]  例如: 90 0")
            return
        if len(vals) < 2:
            print("  ⚠ 至少需要 X 和 Y: <Xmm> <Ymm> [Zmm]  例如: 90 0")
            return
        if len(vals) > 3:
            print("  ⚠ 参数过多, 最多 3 个: <Xmm> <Ymm> [Zmm]")
            return
        x, y = vals[0], vals[1]
        z = vals[2] if len(vals) > 2 else None
        self.arm.move_tool_to(x, y, z)

    # ── 资源管理 ──
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

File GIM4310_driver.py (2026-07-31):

#!/usr/bin/env python3
"""持续读取并显示电机位置信息。按 Ctrl-C 退出。

RS485 自定义协议 V3.03b3 — 波特率 115200, 8N1, 小端字节序。
"""

import math
import os
import struct
import threading
import time

import serial

# ── CRC16_MODBUS ────────────────────────────────────────────────────────────

_CRC16_TABLE = [
    0x0000, 0xC0C1, 0xC181, 0x0140, 0xC301, 0x03C0, 0x0280, 0xC241,
    0xC601, 0x06C0, 0x0780, 0xC741, 0x0500, 0xC5C1, 0xC481, 0x0440,
    0xCC01, 0x0CC0, 0x0D80, 0xCD41, 0x0F00, 0xCFC1, 0xCE81, 0x0E40,
    0x0A00, 0xCAC1, 0xCB81, 0x0B40, 0xC901, 0x09C0, 0x0880, 0xC841,
    0xD801, 0x18C0, 0x1980, 0xD941, 0x1B00, 0xDBC1, 0xDA81, 0x1A40,
    0x1E00, 0xDEC1, 0xDF81, 0x1F40, 0xDD01, 0x1DC0, 0x1C80, 0xDC41,
    0x1400, 0xD4C1, 0xD581, 0x1540, 0xD701, 0x17C0, 0x1680, 0xD641,
    0xD201, 0x12C0, 0x1380, 0xD341, 0x1100, 0xD1C1, 0xD081, 0x1040,
    0xF001, 0x30C0, 0x3180, 0xF141, 0x3300, 0xF3C1, 0xF281, 0x3240,
    0x3600, 0xF6C1, 0xF781, 0x3740, 0xF501, 0x35C0, 0x3480, 0xF441,
    0x3C00, 0xFCC1, 0xFD81, 0x3D40, 0xFF01, 0x3FC0, 0x3E80, 0xFE41,
    0xFA01, 0x3AC0, 0x3B80, 0xFB41, 0x3900, 0xF9C1, 0xF881, 0x3840,
    0x2800, 0xE8C1, 0xE981, 0x2940, 0xEB01, 0x2BC0, 0x2A80, 0xEA41,
    0xEE01, 0x2EC0, 0x2F80, 0xEF41, 0x2D00, 0xEDC1, 0xEC81, 0x2C40,
    0xE401, 0x24C0, 0x2580, 0xE541, 0x2700, 0xE7C1, 0xE681, 0x2640,
    0x2200, 0xE2C1, 0xE381, 0x2340, 0xE101, 0x21C0, 0x2080, 0xE041,
    0xA001, 0x60C0, 0x6180, 0xA141, 0x6300, 0xA3C1, 0xA281, 0x6240,
    0x6600, 0xA6C1, 0xA781, 0x6740, 0xA501, 0x65C0, 0x6480, 0xA441,
    0x6C00, 0xACC1, 0xAD81, 0x6D40, 0xAF01, 0x6FC0, 0x6E80, 0xAE41,
    0xAA01, 0x6AC0, 0x6B80, 0xAB41, 0x6900, 0xA9C1, 0xA881, 0x6840,
    0x7800, 0xB8C1, 0xB981, 0x7940, 0xBB01, 0x7BC0, 0x7A80, 0xBA41,
    0xBE01, 0x7EC0, 0x7F80, 0xBF41, 0x7D00, 0xBDC1, 0xBC81, 0x7C40,
    0xB401, 0x74C0, 0x7580, 0xB541, 0x7700, 0xB7C1, 0xB681, 0x7640,
    0x7200, 0xB2C1, 0xB381, 0x7340, 0xB101, 0x71C0, 0x7080, 0xB041,
    0x5000, 0x90C1, 0x9181, 0x5140, 0x9301, 0x53C0, 0x5280, 0x9241,
    0x9601, 0x56C0, 0x5780, 0x9741, 0x5500, 0x95C1, 0x9481, 0x5440,
    0x9C01, 0x5CC0, 0x5D80, 0x9D41, 0x5F00, 0x9FC1, 0x9E81, 0x5E40,
    0x5A00, 0x9AC1, 0x9B81, 0x5B40, 0x9901, 0x59C0, 0x5880, 0x9841,
    0x8801, 0x48C0, 0x4980, 0x8941, 0x4B00, 0x8BC1, 0x8A81, 0x4A40,
    0x4E00, 0x8EC1, 0x8F81, 0x4F40, 0x8D01, 0x4DC0, 0x4C80, 0x8C41,
    0x4400, 0x84C1, 0x8581, 0x4540, 0x8701, 0x47C0, 0x4680, 0x8641,
    0x8201, 0x42C0, 0x4380, 0x8341, 0x4100, 0x81C1, 0x8081, 0x4040,
]


def _crc16(data: bytes) -> int:
    crc = 0xFFFF
    for b in data:
        crc = (crc >> 8) ^ _CRC16_TABLE[(crc ^ b) & 0xFF]
    return crc


def _require_non_negative(value: float, name: str) -> None:
    """参数校验: 值不能为负数。"""
    if value < 0:
        raise ValueError(f"{name} 不能为负数: {value}")


def _require_finite(value: float, name: str) -> None:
    """参数校验: 值必须为有限数 (禁止 NaN/Inf)。"""
    if not math.isfinite(value):
        raise ValueError(f"{name} 必须是有限数值: {value}")


def _require_uint16(value: int, name: str) -> None:
    """参数校验: 整数必须在 uint16 范围 [0, 65535] 内。"""
    if not 0 <= value <= 0xFFFF:
        raise ValueError(f"{name} 超出 uint16 范围: {value} (须 0~65535)")


def _require_int32(value: int, name: str) -> None:
    """参数校验: 整数必须在 int32 范围 [-2^31, 2^31-1] 内。"""
    if not -0x80000000 <= value <= 0x7FFFFFFF:
        raise ValueError(f"{name} 超出 int32 范围: {value}")


def _clamp(value: int, lo: int, hi: int) -> int:
    """将整数钳制在 [lo, hi] 范围内。"""
    return lo if value < lo else hi if value > hi else value


def _deg_to_encoder(angle_deg: float) -> int:
    """角度 (度) → 编码器计数值。"""
    return int(angle_deg * ENCODER_SCALE)


def _rpm_to_raw(speed_rpm: float) -> int:
    """转速 (rpm) → 协议原始值 (0.01 rpm)。"""
    return int(speed_rpm * 100)


def _scale_bipolar_to_raw(value: float, max_abs: float, raw_max: int) -> int:
    """将 [-max_abs, +max_abs] 映射到 [0, raw_max], 钳制越界值。"""
    if max_abs <= 0:
        return 0
    raw = round((value + max_abs) / (2.0 * max_abs) * raw_max)
    return _clamp(raw, 0, raw_max)


def _scale_unipolar_to_raw(value: float, max_val: float, raw_max: int) -> int:
    """将 [0, max_val] 映射到 [0, raw_max], 钳制越界值。"""
    if max_val <= 0:
        return 0
    raw = round(value / max_val * raw_max)
    return _clamp(raw, 0, raw_max)


# ── 协议常量 ─────────────────────────────────────────────────────────────────

HEADER_HOST = 0xAE
HEADER_SLAVE = 0xAC
FRAME_HEADER_LEN = 5
FRAME_CRC_LEN = 2
MAX_PAYLOAD_LEN = 64

ENCODER_RESOLUTION = 16384
ANGLE_SCALE = 360.0 / ENCODER_RESOLUTION
ENCODER_SCALE = 1.0 / ANGLE_SCALE  # 度数 → 编码器值 (精确互为倒数)

# ── MIT 运控默认参数 ────────────────────────────────────────────────────────

MIT_DEFAULT_POS_MAX_RAD = 95.5        # 位置最大值 (rad)
MIT_DEFAULT_VEL_MAX_RAD_S = 45.0      # 速度最大值 (rad/s)
MIT_DEFAULT_T_MAX_NM = 18.0           # 力矩最大值 (N·m)
MIT_DEFAULT_POS_KP_MAX = 500          # 位置 KP 最大值
MIT_DEFAULT_VEL_KD_MAX = 5            # 速度 KD 最大值

MODE_NAMES = {0: "关闭", 1: "电压控制", 2: "Q轴电流控制", 3: "速度控制", 4: "位置控制"}

# ── 配置 (按需修改) ──────────────────────────────────────────────────────────

SERIAL_PORT = "/dev/serial/by-id/usb-FTDI_USB__-__Serial_Converter_FTBVQPDL-if00-port0"
MOTOR_ADDR = 0x01
BAUDRATE = 921600
READ_INTERVAL = 0.02


# ── 电机通信 ─────────────────────────────────────────────────────────────────
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

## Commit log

2026-07-29 摄像头驱动
2026-07-29 舵机驱动
2026-07-29 调整窗口
2026-07-29 高精度检测
2026-07-29 几何中心
2026-07-30 单纯匹配
2026-07-30 递归配对
2026-07-30 三个装配
2026-07-30 三个正常了
2026-07-30 拼接ok！
2026-07-30 勉强能拼
2026-07-31 超绝爆炸图
2026-07-31 坐标移动
2026-07-31 准备ok！！
2026-07-31 主逻辑开头
2026-07-31 能行，笛卡尔坐标
2026-07-31 执行器坐标！
2026-07-31 化简～！
2026-07-31 坐标系对齐！！
2026-07-31 读取坐标！
2026-07-31 舵机转动！
2026-07-31 trans！
2026-07-31 爆炸图！
2026-07-31 超级拼装！
2026-07-31 完全体，爆炸图
2026-07-31 完美更加稳健的识别！
2026-07-31 防止碰撞
2026-07-31 修了一半bug
2026-07-31 完成！@
2026-07-31 设置零点
2026-08-09 docs: 添加项目简介(26电赛E题)
2026-09-06 docs: 添加 26 电赛机械臂完赛演示视频
2026-09-15 添加 MIT 许可证
2026-09-15 更正许可证署名
2026-09-15 添加机械臂结构模型文件（SolidWorks 零件与装配体 5 件）
    [大臂.SLDPRT, 底座.SLDPRT, 电机.SLDPRT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]
